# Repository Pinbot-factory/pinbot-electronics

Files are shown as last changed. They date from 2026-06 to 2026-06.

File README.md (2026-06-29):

**Pinbot** is an open-source platform for quickly building test jigs for electronics QA. The platform is made up of [mechanical fixture](https://github.com/Pinbot-factory/pinbot-mechanical), control electronics (this repo), jig-level software and backend to store all test results.

## Pinbot electronics
This repo is dedicated for electronics of a typical Pinbot jig. At a moment it is a compact carrier board for Raspberry Pi Zero [2](https://www.jeffgeerling.com/blog/2021/look-inside-raspberry-pi-zero-2-w-and-rp3a0-au/). The board also can be used with regular size RPis thru HAT connector (J3).

**It features:**
- 16 channels GPIO (0-24V) thru TCA9535
- 8 channels ADC (12 bit, 0-24V) thru ADS1015
- 4 signal relays
- USB hub
    - 4 downstream ports (3 USB-A + 1 as a pins on J2)
    - Per-port power control
    - Per-port fault signals for error and power failures handling
- Qwiic connector for easy I2C expansion
- Raspberry Pi 40-pin GPIO header with SPI, I2C, UART, etc
- USB-C for power supply
- User leds, test points, basic signal lines protection and more.

Carrier board is 114x65mm to fit perfectly into [Pinbot's chassis](https://github.com/Pinbot-factory/pinbot-mechanical/tree/main/chassis). You can use it as a test engine for a small projects and supply them (as well as connected USB periphery) with 5V.

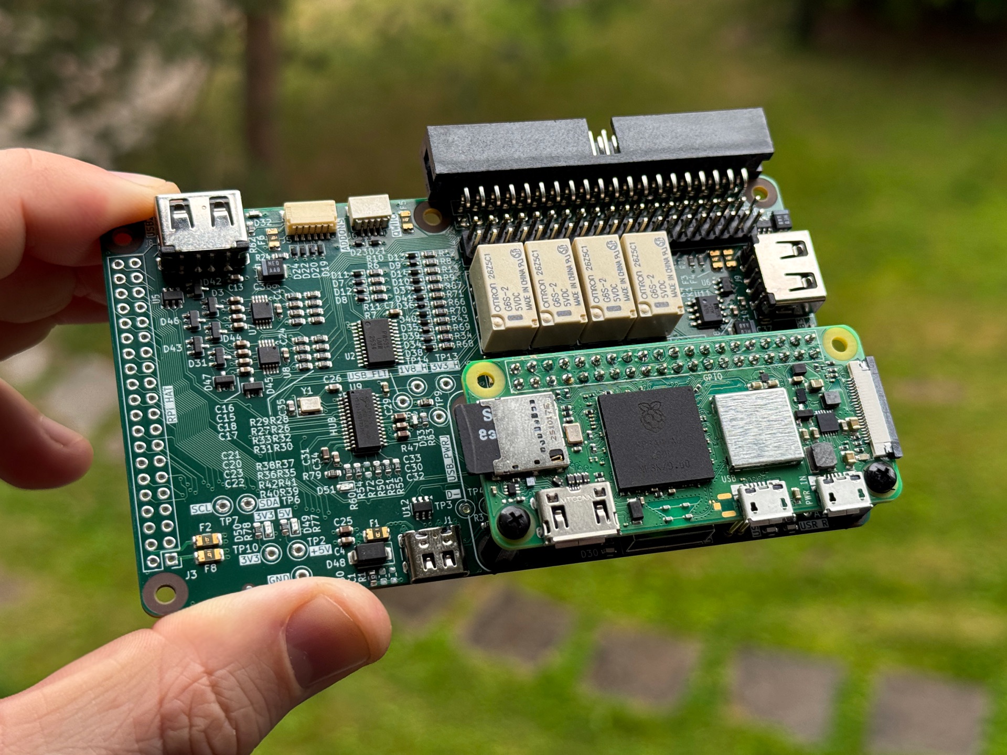
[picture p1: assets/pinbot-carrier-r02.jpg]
Pinbot PCBA


The repo includes KiCAD source files, generated gerbers, BOM, and everything to produce it on your own. Python *library and software examples* are also available and briefly [documented](sw_examples/README.md).

## License
- [GNU GPLv3](https://www.gnu.org/licenses/gpl-3.0.en.html) for **software**: firmware, libraries, generators, tools, examples, etc
- [CERN-OHL-S](https://cern-ohl.web.cern.ch/) for **hardware**: PCB schematic, layout, BOM, gerbers, 3D models, g-codes, etc.
- [CC BY-SA 4.0](https://creativecommons.org/licenses/by-sa/4.0/deed.en) is for docs, pictures, articles, video, assets, etc.

Pinbot projects structure may mix different sources and artifacts — check corresponding dirrectories for `LICENSE` file.

-----------
*This project is sponsored by [NLnet](https://nlnet.nl/) as a part of [NGI Zero Review](https://nlnet.nl/NGI0/review/) program.*
<p align="left">
    
</p>

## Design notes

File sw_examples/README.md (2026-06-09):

# Pinbot lib
The lib written specifically for the **Pinbot r0.2** board and simplifies access to all of its peripherals (relays, LEDs, and the USB hub) over the I2C bus. It also provides convenient access to 16 general-purpose I/O channels. See Pinbot [schematics](../docs/pinbot-carrier-schematic.pdf) for detailed HW architecture.

## Installation and usage
Simply copy the entire directory, including its internal structure and files, to the Raspberry Pi that controls the Pinbot board.

Here is a simple example of using the lib with a Pinbot board.
```python
import pinbot

# Init Pinbot board with it's default periphery config
board = pinbot.init_default()

board.led.on(pinbot.RED)
board.relay.close(1)

board.signal.write(
    "GPIO0",
    state=pinbot.HIGH
)

state = board.signal.read("GPIO0")
print(f"GPIO0 state = {state}")
```

You can find additional usage examples in the repo, along with a couple of tools for debugging your test jigs.

## IO1 signals mapping and pinout
TCA9535  on I2C ddress: **0x20**. General purpose IO expander. Protected GPIO channels (0-24V)

| Port | Pin | Signal Name | Default mode | J2 pin |
|---|-----|---|---|---|
| 0 | 0 | GPIO0 | out | 12 |
| 0 | 1 | GPIO1 | out | 11 |
| 0 | 2 | GPIO2 | out | 14 |
| 0 | 3 | GPIO3 | out | 13 |
| 0 | 4 | GPIO4 | out | 16 |
| 0 | 5 | GPIO5 | out | 15 |
| 0 | 6 | GPIO6 | out | 18 |
| 0 | 7 | GPIO7 | out | 17 |
| 1 | 0 | GPIO8 | out | 22 |
| 1 | 1 | GPIO9 | out | 21 |
| 1 | 2 | GPIO10 | out | 24 |
| 1 | 3 | GPIO11 | out | 23 |
| 1 | 4 | GPIO12 | out | 26 |
| 1 | 5 | GPIO13 | out | 25 |
| 1 | 6 | GPIO14 | out | 28 |
| 1 | 7 | GPIO15 | out | 27 |

## IO2 signals mapping and pinout
TCA9535 on I2C address: **0x21**. Relay control, USB control, alerts and status LEDs.

| Port | Pin | Signal Name | Default mode | Comment |
|---|-----|---|---|---|
| 0 | 0 | RELAY1 | out | Relay 1 control, J4 pins 1, 3, 5 |
| 0 | 1 | RELAY2 | out | Relay 2 control, J4 pins 7, 9, 11|
| 0 | 2 | RELAY3 | out | Relay 3 control, J4 pins 13, 15, 17 |
| 0 | 3 | RELAY4 | out | Relay 4 control, J4 pins 19, 21, 23 |
| 0 | 4 | ALERT0 | in | ADS1015 alert 0 |
| 0 | 5 | ALERT1 | in | ADS1015 alert 1 |
| 0 | 6 | USR_R | out | User **red** LED |
| 0 | 7 | USR_G | out | User **green** LED |
| 1 | 0 | USB_FLT1 | in | USB port 1 fault, **active low** |
| 1 | 1 | USB_FLT2 | in | USB port 2 fault, **active low** |
| 1 | 2 | USB_FLT3 | in | USB port 3 fault, **active low** |
| 1 | 3 | USB_FLT4 | in | USB port 4 fault, **active low** |
| 1 | 4 | USB_EN1 | out | USB port 1 enable, **active low** |
| 1 | 5 | USB_EN2 | out | USB port 2 enable, **active low** |
| 1 | 6 | USB_EN3 | out | USB port 3 enable, **active low** |
| 1 | 7 | USB_EN4 | out | USB port 4 enable, **active low** |

Pinbot is a simple library written in Python that works via `smbus2` and `lgpio` (both are included in the standard Raspbian OS distribution). It is suitable for getting familiar with the concept of test jigs and organizing "end-of-line" tests across batches of hundreds and thousands of units. However, do not expect impressive performance or the outstanding stability required for industrial automation.

## TODO
- Proper ADC lib integration
  - More ADC examples
- Example of how to use more than one instance of `pinbot()` in concurent scripts
- Detailed description on USB-hub behaviour
- Implement Active-Low mapping to `pinbot.signal.info()`
- Document whole lib calls
- Ensure USB hub availability in OS

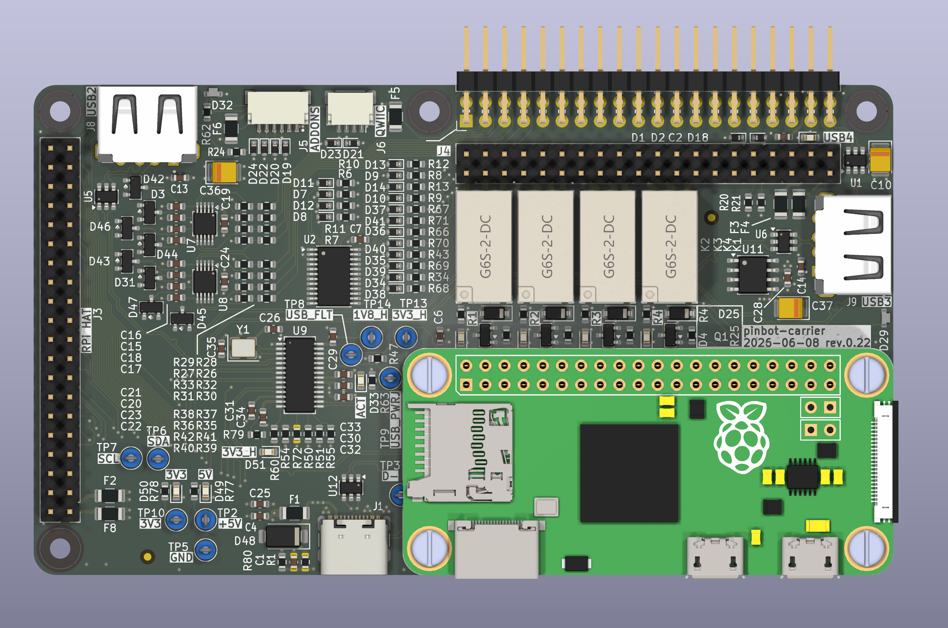
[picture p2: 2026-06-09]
assets/pinbot-pcba.png

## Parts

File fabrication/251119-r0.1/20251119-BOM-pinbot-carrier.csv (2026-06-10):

Reference | Value | Footprint | Qty | DNP | LCSC Part # | Mouser Part #
A1 | Raspberry Pi Zero v1.3 | Raspberry_Pi_Zero_v.1.3_Hat:RASPI_ZERO_FULL | 1
C1,C4,C5,C6,C7,C9,C10,C17,C18,C19,C20,C21,C22,C23 | 0.1uFx50V | Capacitor_SMD:C_0603_1608Metric | 14 |  | C282519 | CGA3E2X7R1H104M080AA
C2 | 0.01uFx50V | Capacitor_SMD:C_0603_1608Metric | 1 |  | C100042 | 06031C103K4T4A
C3,C8,C12,C13,C14 | 100uFx16V | Capacitor_SMD:CP_Elec_6.3x5.4 | 5 |  | C129250 | UWT1C101MCL1GB
C11,C15,C16 | 10uFx10V | Capacitor_SMD:C_0603_1608Metric | 3 |  | C2959727 | GRM188Z71A106MA73J
D1,D2,D3,D4,D6,D7,D8,D9 | LTST-S270KGKT | LED_0603_1608Metric_side:LED_0603_1608Metric_side | 8 |  | C125113 | LTST-S270KGKT
D5 | LTST-S270KRKT | LED_0603_1608Metric_side:LED_0603_1608Metric_side | 1 |  | C125114 | LTST-S270KRKT
D10,D11,D12,D13,D14,D15,D16,D17 | ESD5Z3.3T5G | Diode_SMD:D_SOD-523 | 8 |  | C22440077 | ESD5Z3.3T5G
F1 | MF-NSMF200-2 | Fuse:Fuse_1206_3216Metric | 1 |  | C89656 | MF-NSMF200-2
H1,H2,H3,H4 | MountingHole | MountingHoles:MountingHole_3.2mm_M3_keepouts | 4 | DNP
J1 | USB4105-GF-A-120 | Connector_USB:USB_C_Receptacle_GCT_USB4105-xx-A_16P_TopMnt_Horizontal | 1 |  | C709358 | USB4105-GF-A-120
J2 | Conn_02x20_Odd_Even | Connector_PinSocket_2.54mm:PinSocket_2x20_P2.54mm_Vertical | 1 |  | C2977589
J3 | HC-1.0-4PWT | Connector_JST:JST_SH_SM04B-SRSS-TB_1x04-1MP_P1.00mm_Horizontal | 1 |  | C2845363 | 10147606-00004LF
J4 | SM06B-SRSS-TB | SM06B-SRSS-TB:JST_SM06B-SRSS-TB | 1 |  | C160405 | 10147606-00006LF
J5,J6,J7 | USB_A | USB1125-GF-B:GCT_USB1125-GF-B_REVA | 3 |  | C5984324 | USB1125-GF-B
JP1,JP2 | SolderJumper_2_Open | Jumper:SolderJumper-2_P1.3mm_Open_RoundedPad1.0x1.5mm | 2 | DNP
K1,K2,K3,K4 | EC2-5SNU | Relay_THT:Relay_DPDT_Kemet_EC2 | 4 |  | C2153173 | EC2-5SNU
R1,R2,R3,R4,R12,R13,R14,R15 | 820k | Resistor_SMD:R_0603_1608Metric | 8 |  | C2907070 | ERJ-3EKF8203V
R5,R6,R8,R9,R16,R17,R20,R25 | 120k | Resistor_SMD:R_0603_1608Metric | 8 |  | C2930027 | CRGCQ0603F120K
R7 | 1M | Resistor_SMD:R_0603_1608Metric | 1 |  | C107698 | ASC0603-1M0FT5
R10,R11 | 5.1k | Resistor_SMD:R_0603_1608Metric | 2 |  | C2907114 | ERJ-3EKF5101V
R18,R19,R21,R22,R23,R24,R26,R27,R35,R36,R37,R42,R43 | 10k | Resistor_SMD:R_0603_1608Metric | 13 |  | C2907113 | RMC1/16K1002DTP
R28 | 100R | Resistor_SMD:R_0603_1608Metric | 1 |  | C2907089 | CRT0603-DY-1000ELF
R29,R30,R31,R32,R33,R34,R39,R40,R41 | 330R | Resistor_SMD:R_0603_1608Metric | 9 |  | C23138 | RMCF0603FT330R
R38 | 2.7k | Resistor_SMD:R_0603_1608Metric | 1 |  | C13167 | AC0603FR-102K7L
U1 | TCA9535PWR | Package_SO:TSSOP-24_4.4x7.8mm_P0.65mm | 1 |  | C22396388 | TCA9535PWR
U2,U7 | ADS1015IDGS | Package_SO:TSSOP-10_3x3mm_P0.5mm | 2 |  | C193969 | ADS1015IDGS
U8 | 74HC04 | Package_SO:SOIC-14_3.9x8.7mm_P1.27mm | 1 |  | C5590 | 74HC04D,653
U9,U10,U11,U12 | ZXBM5210-S | Package_SO:SOIC-8_3.9x4.9mm_P1.27mm | 4 |  | C20627211 | ZXBM5210-S
U13,U19 | MIC2026-2xM | Package_SO:SOIC-8_3.9x4.9mm_P1.27mm | 2 |  | C148072 | MIC2026-2YM
U14,U15,U16,U17 | USBLC6-2SC6 | Package_TO_SOT_SMD:SOT-23-6 | 4 |  | C5180249 | USBLC6-2SC6
U18 | FE1.1s | Package_SO:SSOP-28_3.9x9.9mm_P0.635mm | 1 |  | C9359
Y1 | 12MHz | Crystal:Crystal_SMD_3225-4Pin_3.2x2.5mm | 1 |  | C70565 | ECS-120-12-33-AEN-TR

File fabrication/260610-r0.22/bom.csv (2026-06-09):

Designator | Footprint | Quantity | Value | LCSC Part #
C1 | 0603 | 1 | 0.01uFx50V | C100042
C10, C36, C37, C9 | CP_EIA-3528-21_Kemet-B | 4 | 100uFx10V | C600583
C12, C13, C14, C15, C16, C17, C18, C19, C2, C20, C21, C22, C23, C24, C27, C28, C29, C30, C34, C4, C7, C8 | 0603 | 22 | 0.1uFx50V | C282519
C25, C31, C32, C33, C6 | 0603 | 5 | 10uFx10V | C2959727
C26, C35 | 0603 | 2 | 14pFx50V | C5360816
D1, D10, D11, D12, D13, D14, D19, D2, D20, D21, D22, D23, D24, D34, D35, D36, D37, D38, D39, D40, D41, D7, D8, D9 | D_SOD-523 | 24 | ESD5Z3.3T5G | C22440077
D15 | 0603 | 1 | LTST-S270KRKT | C125114
D16, D29, D30, D32 | 0603 | 4 | LTST-S270KGKT | C125113
D17, D18, D4, D5, D6 | 0603 | 5 | 19-21/GHC-YR1S2/4T | C2986048
D25, D26, D27, D28 | D_SOD-123 | 4 | MMSD4148 | C11177
D3, D31, D42, D43, D44, D45, D46, D47, D52, D53, D54, D55 | SOT-23 | 12 | BAT54S | C19726
D33, D49, D50, D51 | 0603 | 4 | XL-1608SURC-06 | C965799
D48 | D_SMA | 1 | SMAJ5.0A | C83329
F1 | 1206 | 1 | MF-NSMF200-2 | C89656
F2, F3, F4, F5, F6, F8 | 1206 | 6 | MF-NSMF110-2 | C89654
J1 | USB_C_Receptacle_GCT_USB4105-xx-A_16P_TopMnt_Horizontal | 1 | USB4105-GF-A-120 | C709358
J2 | PinHeader_2x20_P2.54mm_Horizontal | 1 | Conn_02x20_Odd_Even | C124369
J3 | PinHeader_2x20_P2.54mm_Vertical | 1 | Raspberry_Pi_4 | C19190512
J4 | PinHeader_2x20_P2.54mm_Vertical | 1 | Conn_02x20_Odd_Even | C19190512
J5 | JST_SM06B-SRSS-TB | 1 | SM06B-SRSS-TB | C160405
J6 | JST_SH_SM04B-SRSS-TB_1x04-1MP_P1.00mm_Horizontal | 1 | HC-1.0-4PWT | C2845363
J7, J8, J9 | GCT_USB1125-GF-B_REVA | 3 | USB_A | C5984324
K1, K2, K3, K4 | G6S-2-5V | 4 | G6S-2-5V | C32776
Q1, Q2, Q3, Q4 | SOT-23 | 4 | 2N7002 | C81445
R1 | 0603 | 1 | 1M | C107698
R10, R11, R12, R13, R16, R17, R18, R19, R25, R27, R29, R31, R33, R34, R36, R38, R40, R42, R43, R44, R45, R46, R47, R54, R55, R56, R57, R58, R59, R6, R66, R67, R68, R69, R7, R70, R71, R72, R73, R74, R75, R76, R8, R9 | 0603 | 44 | 10k | C98220
R14, R15, R20, R21, R4, R48, R49, R5, R52, R53, R61, R62, R63, R64, R65, R77, R78, R79 | 0603 | 18 | 330R | C23138
R2, R3 | 0603 | 2 | 5.1k | C2907114
R24 | 0603 | 1 | 100R | C2907089
R26, R28, R30, R32, R35, R37, R39, R41 | 0603 | 8 | 110k | C25805
R50, R51 | 0603 | 2 | 51k | C2907180
R60 | 0603 | 1 | 2.7k | C13167
R80 | 0603 | 1 | 0 | C95177
U1, U12, U4, U5, U6 | SOT-23-6 | 5 | USBLC6-2SC6 | C5180249
U10, U11 | SOIC-8_3.9x4.9mm_P1.27mm | 2 | MIC2026-2xM | C148072
U2, U3 | TSSOP-24_4.4x7.8mm_P0.65mm | 2 | TCA9535PWR | C22396388
U7, U8 | TSSOP-10_3x3mm_P0.5mm | 2 | ADS1015IDGS | C193969
U9 | SSOP-28_3.9x9.9mm_P0.635mm | 1 | FE1.1s | C9359
Y1 | Crystal_SMD_3225-4Pin_3.2x2.5mm | 1 | 12MHz | C70565

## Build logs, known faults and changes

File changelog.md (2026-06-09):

# Changelog

## 20260531 (r0.21)
- bugfix: TCA SCL-SDA reversed
- schematic minor updates: I2C addresses, netlabels, cleanup
- silkscreen fixes
- sw_examples added together with `pinbot` Python lib

## 20260508 (r0.2)
- Layout, schematic and BOM updated completely
- 2nd TCA9535 (TCA2) added
- USB hub schematic reworked heavily
- All periphery control pins is connected with TCA2 io expander
- ADS1015 alert pins added to TCA2
- New ADC dividers (x/12) and RC-filters
- Relays swapped from latch-type to normally-closed type
- 4 layers layout with impedance control
- Additional RPi compatible connector. Board can be used as RPi HAT now.
- 2 user leds
- Protection for all IO and external boards
- Debug features like test points, indicators, fiducials

## 20251119
- Project renamed
- Directory structure cleanup
- Manufacturing files updated

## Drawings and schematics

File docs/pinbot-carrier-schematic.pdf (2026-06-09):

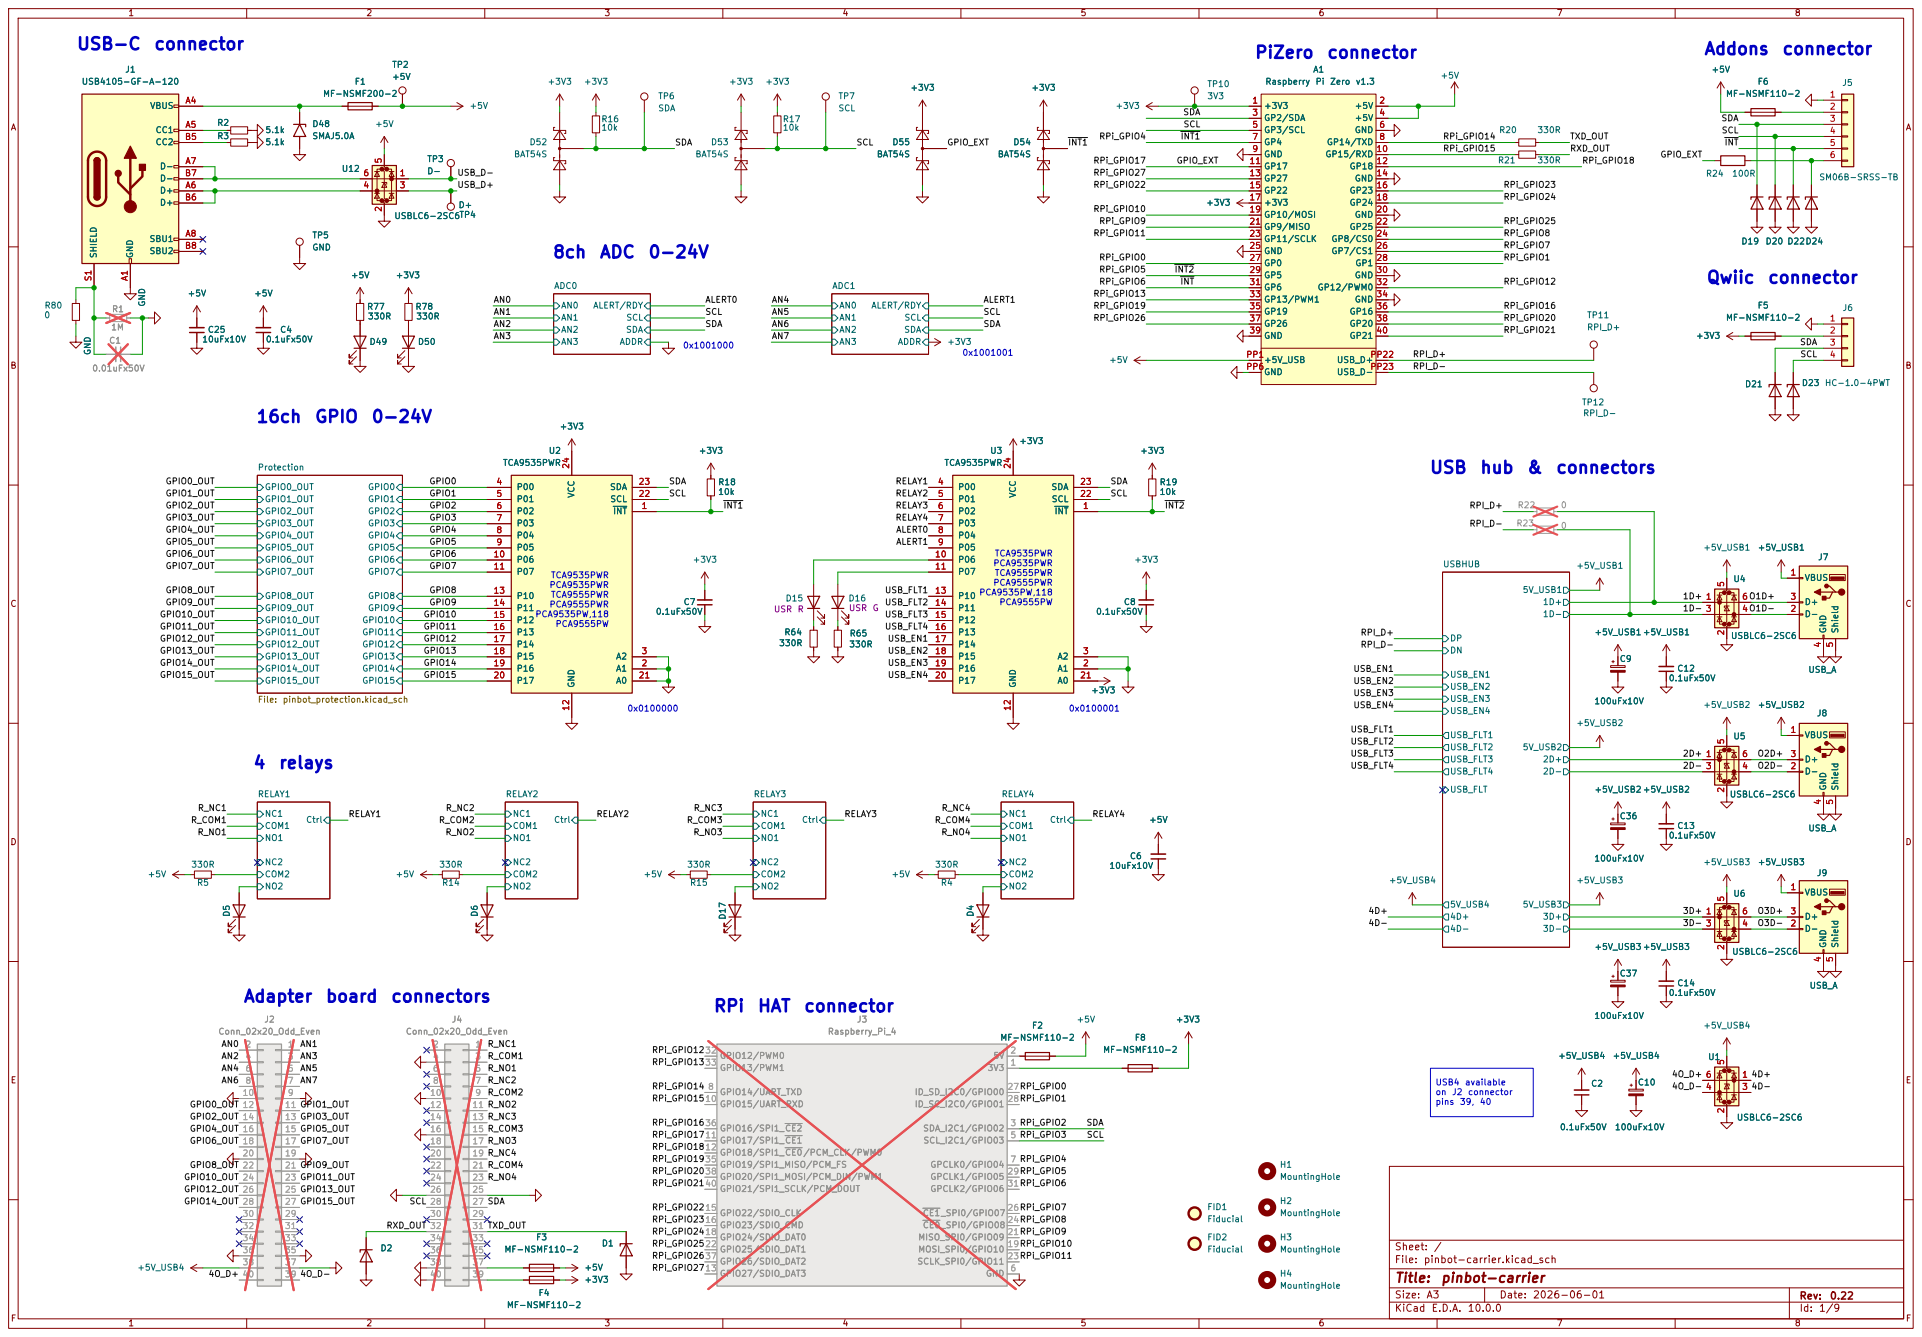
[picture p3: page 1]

Id: 1/9 Title: pinbot-carrier File: pinbot-carrier.kicad_sch Sheet: /

Size: A3 | Rev: 0.22

F Date: 2026-06-01 KiCad E.D.A. 10.0.0

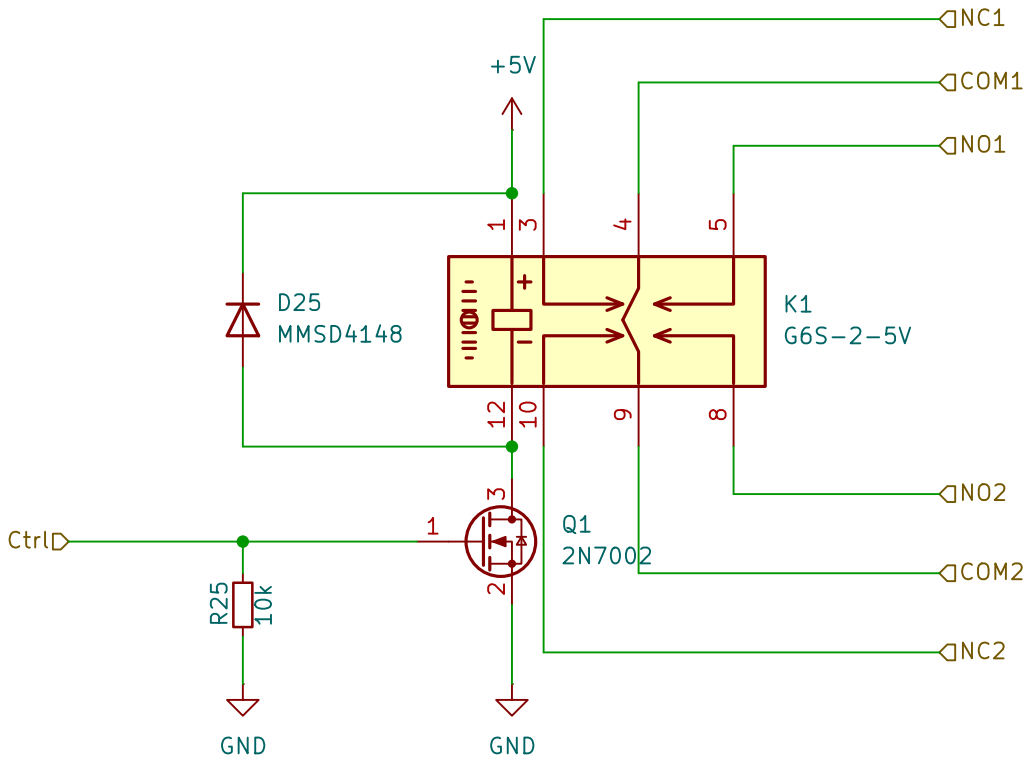
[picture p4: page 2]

Size: A4 | Rev: 0.22

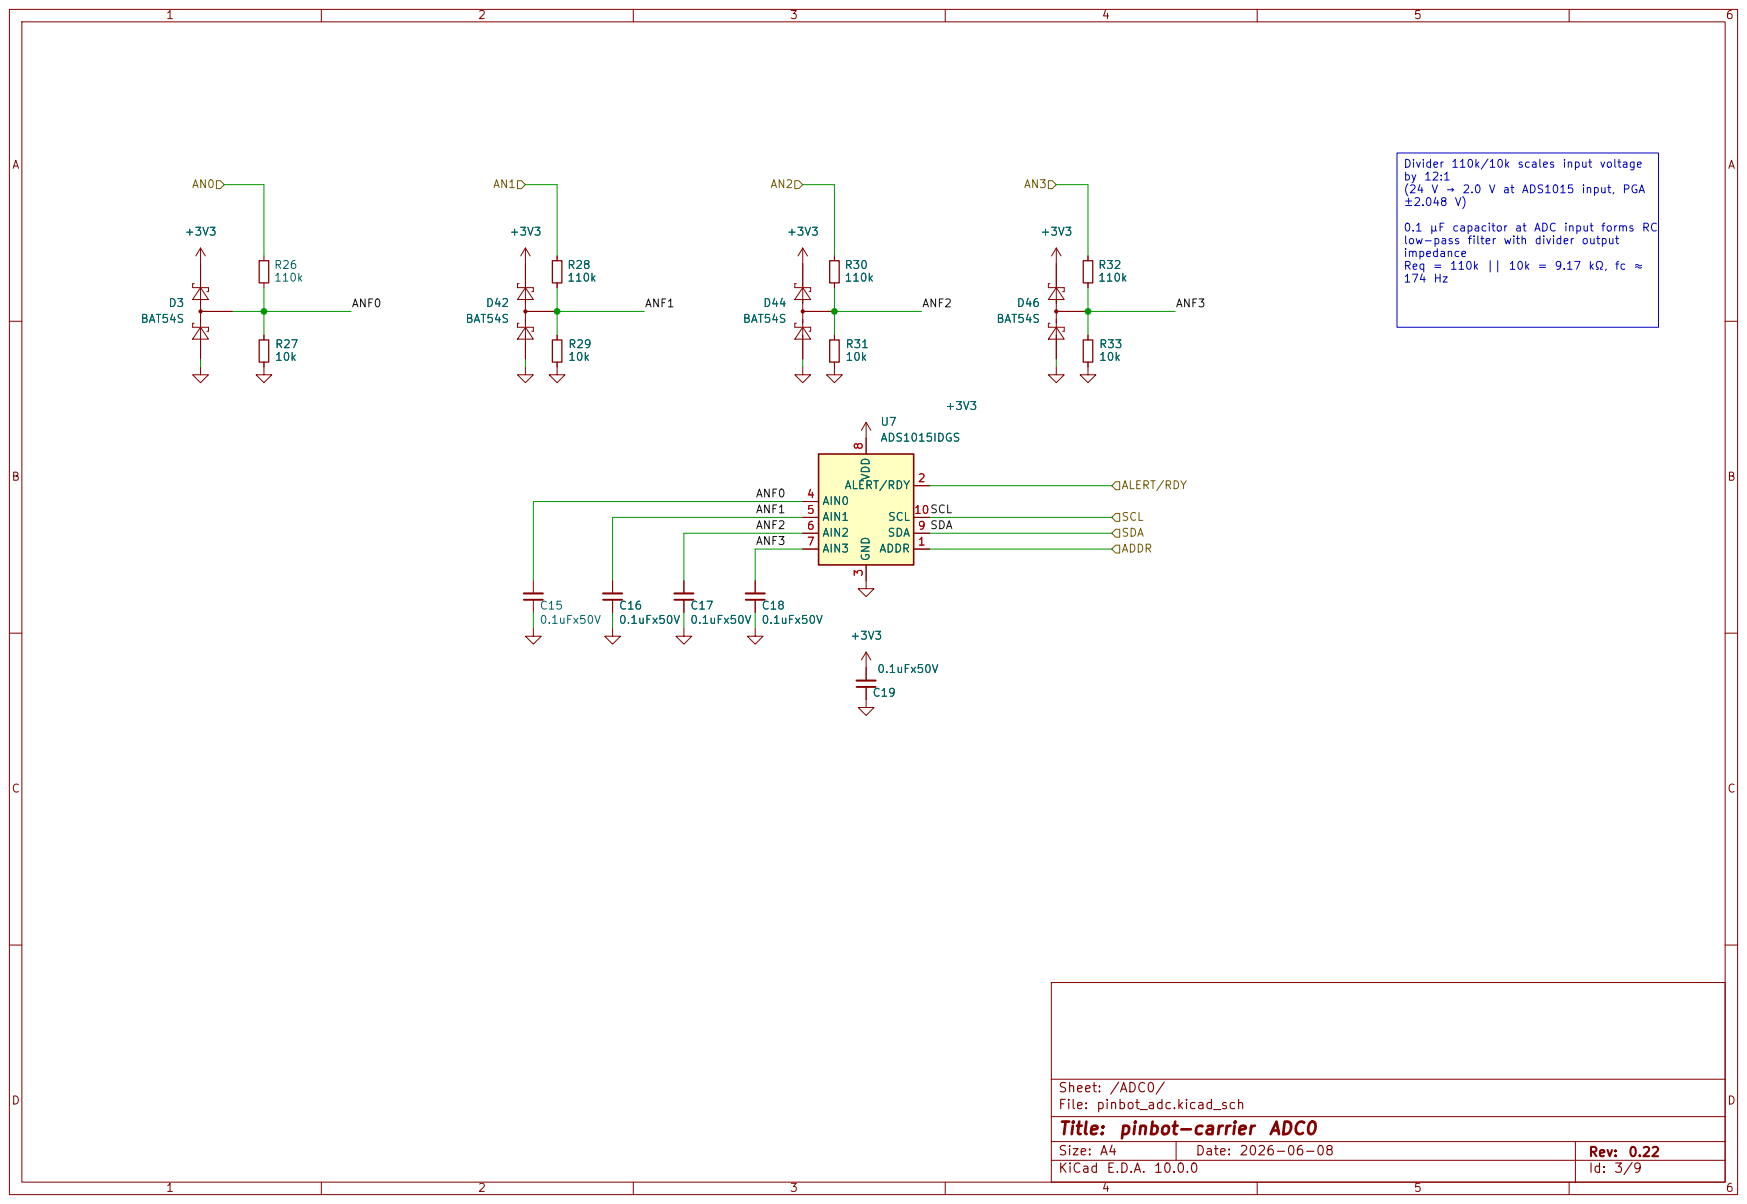
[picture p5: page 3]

0.1 µF capacitor at ADC input forms RC
low-pass filter with divider output
impedance
Req = 110k || 10k = 9.17 kΩ, fc ≈

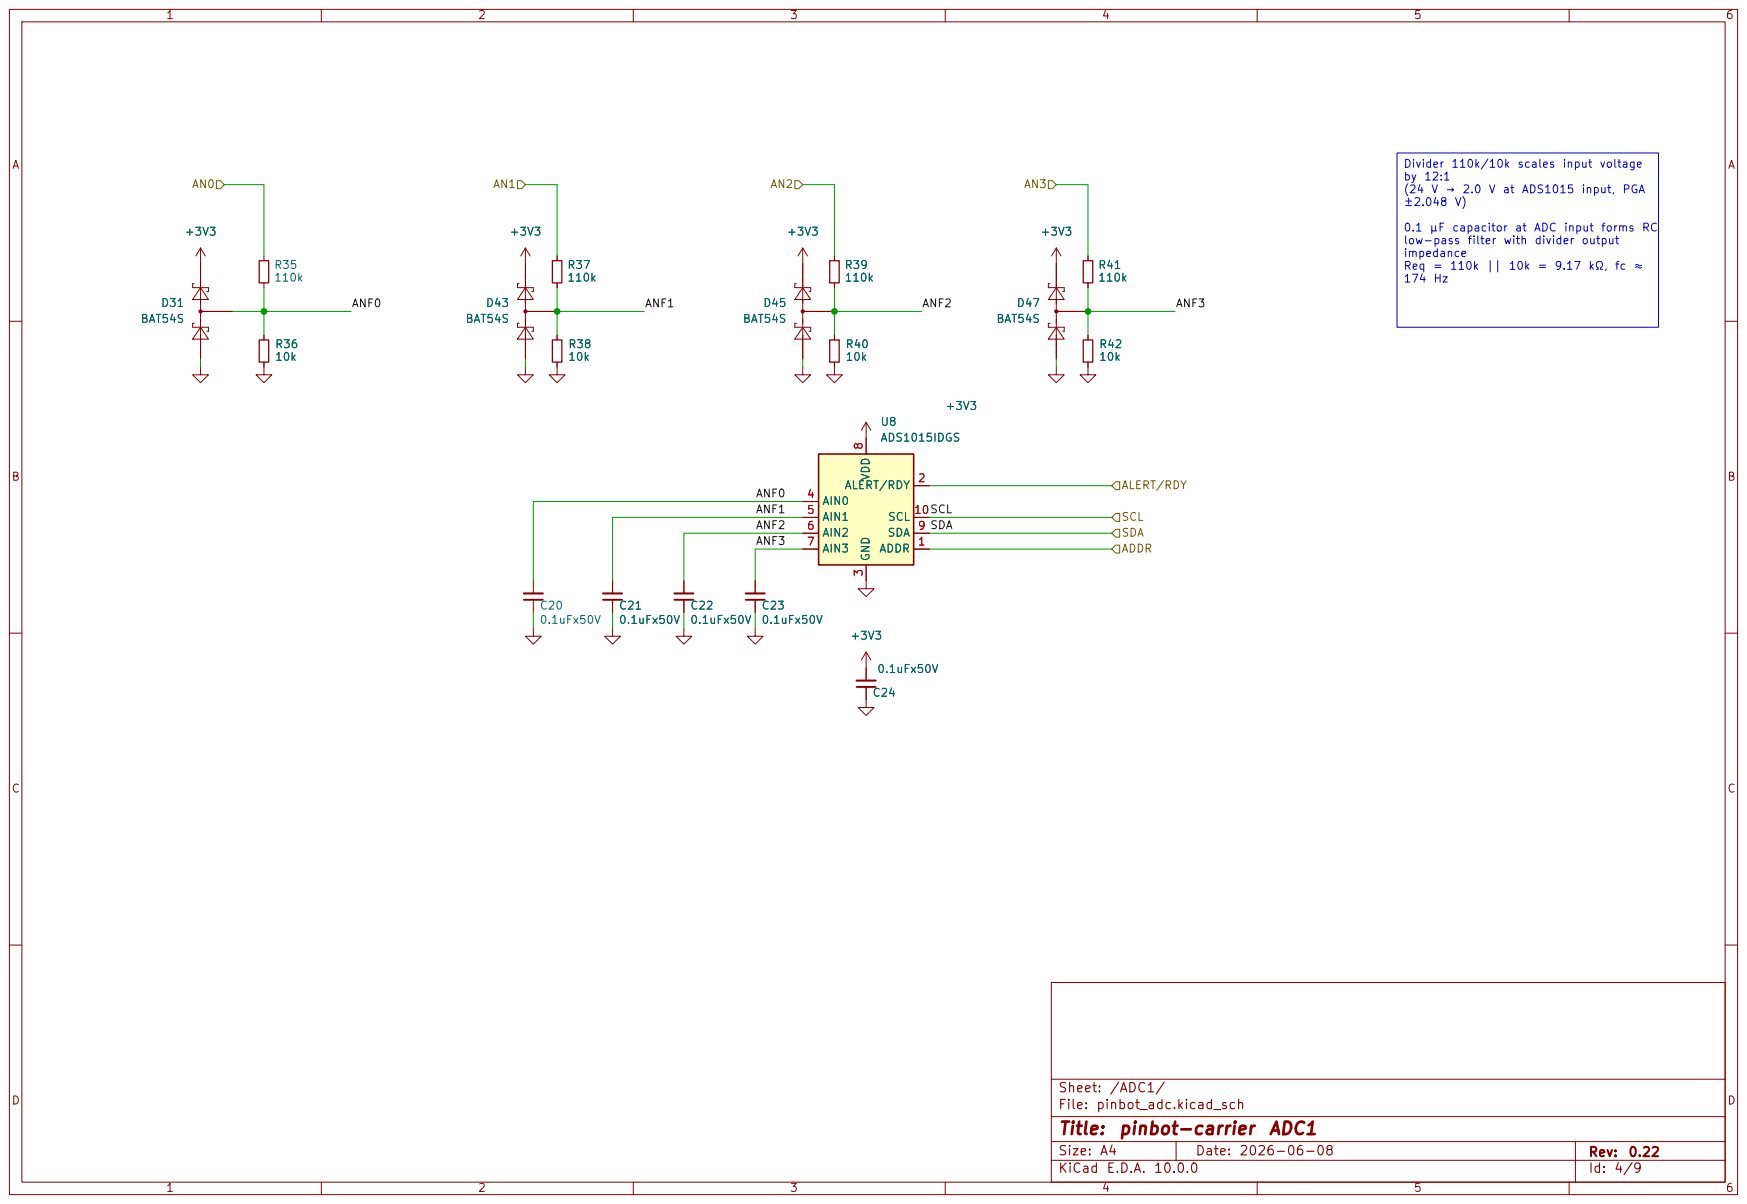
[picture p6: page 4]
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

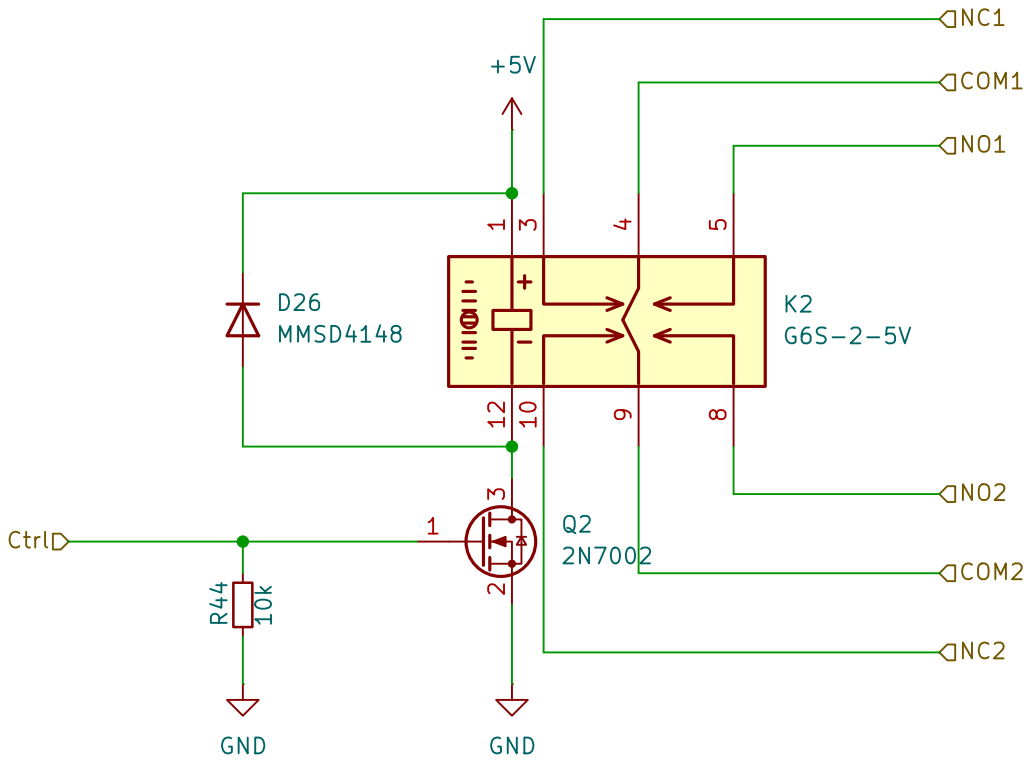
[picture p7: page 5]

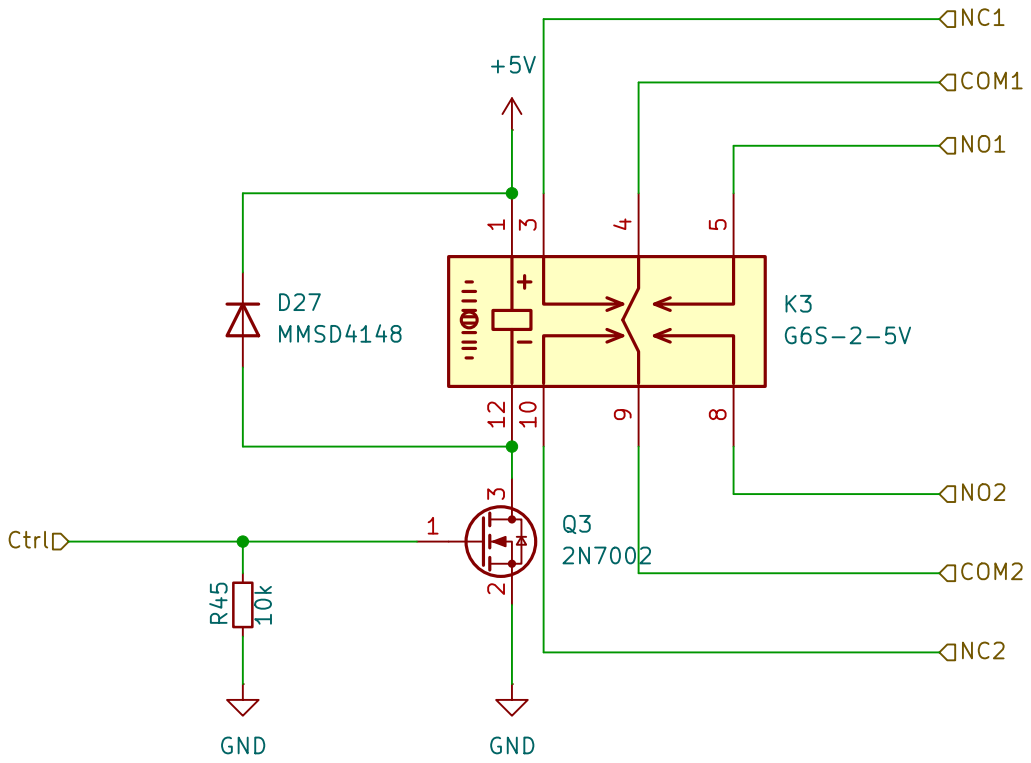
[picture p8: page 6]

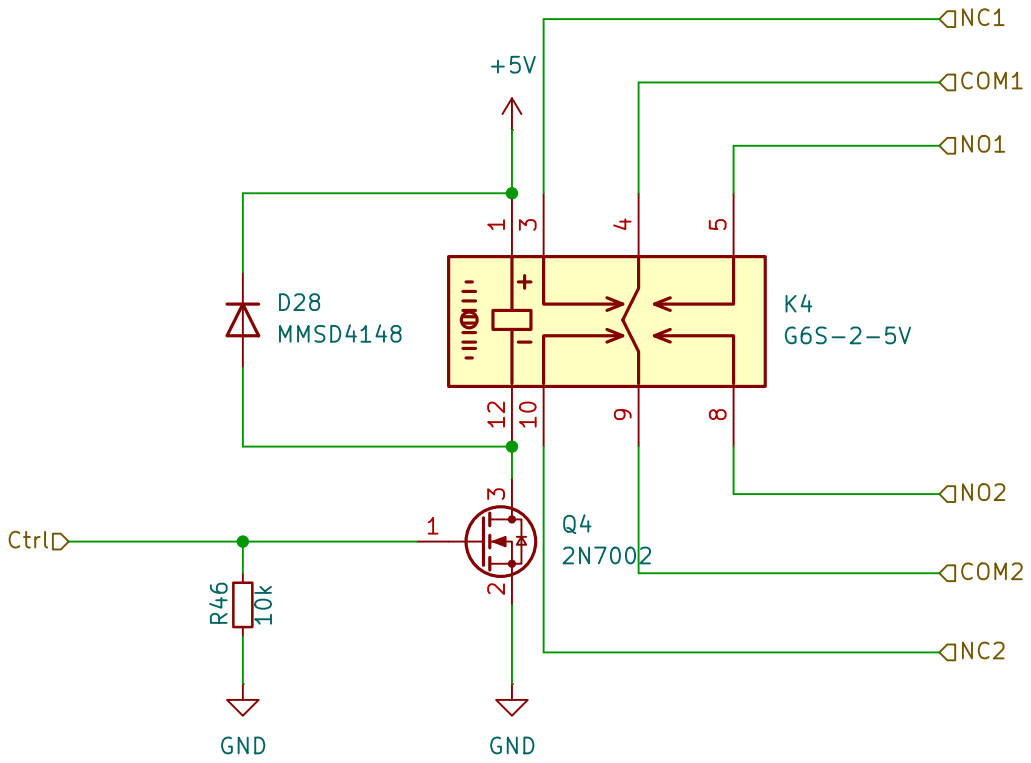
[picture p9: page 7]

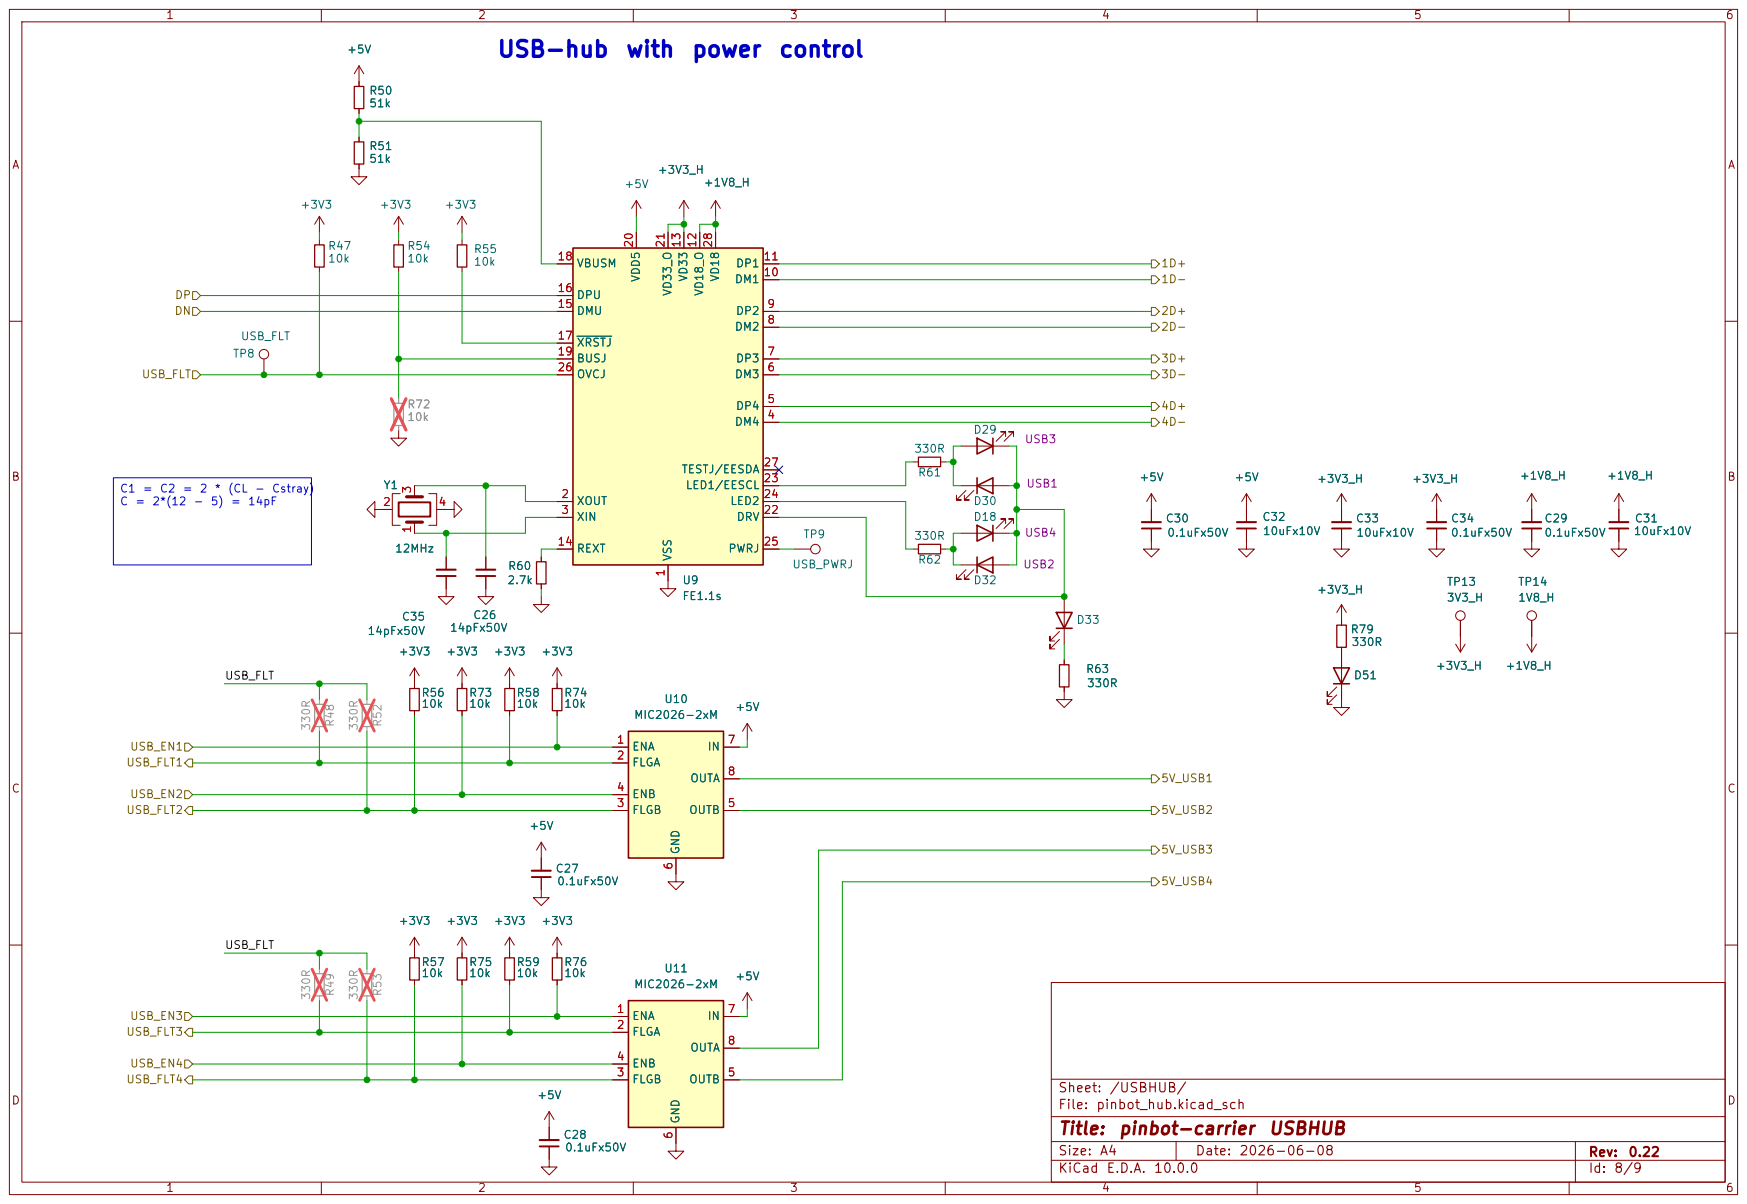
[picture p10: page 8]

Sheet: /USBHUB/
D Date: 2026-06-08 KiCad E.D.A. 10.0.0
File: pinbot_hub.kicad_sch
Title: pinbot-carrier USBHUB

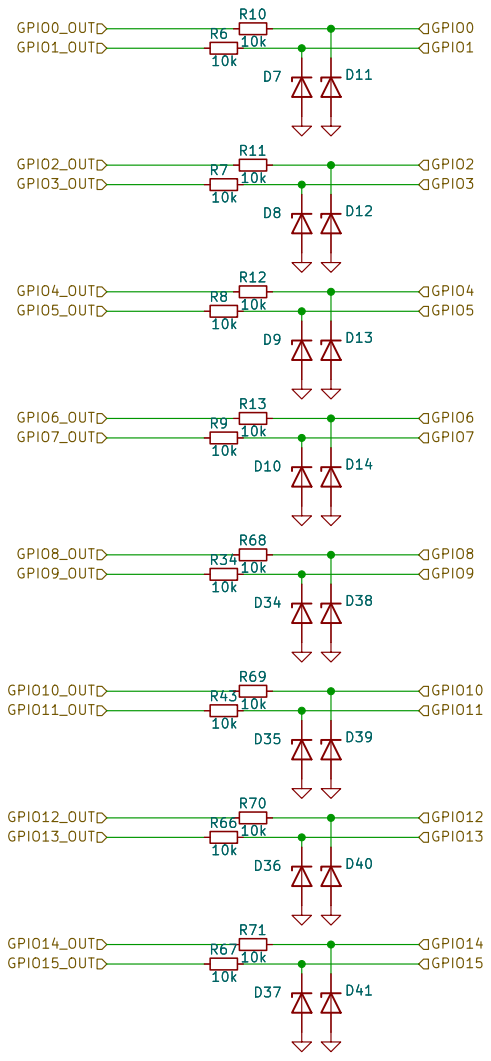
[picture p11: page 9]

Sheet: /Protection/
File: pinbot_protection.kicad_sch
Title: pinbot-carrier Protection

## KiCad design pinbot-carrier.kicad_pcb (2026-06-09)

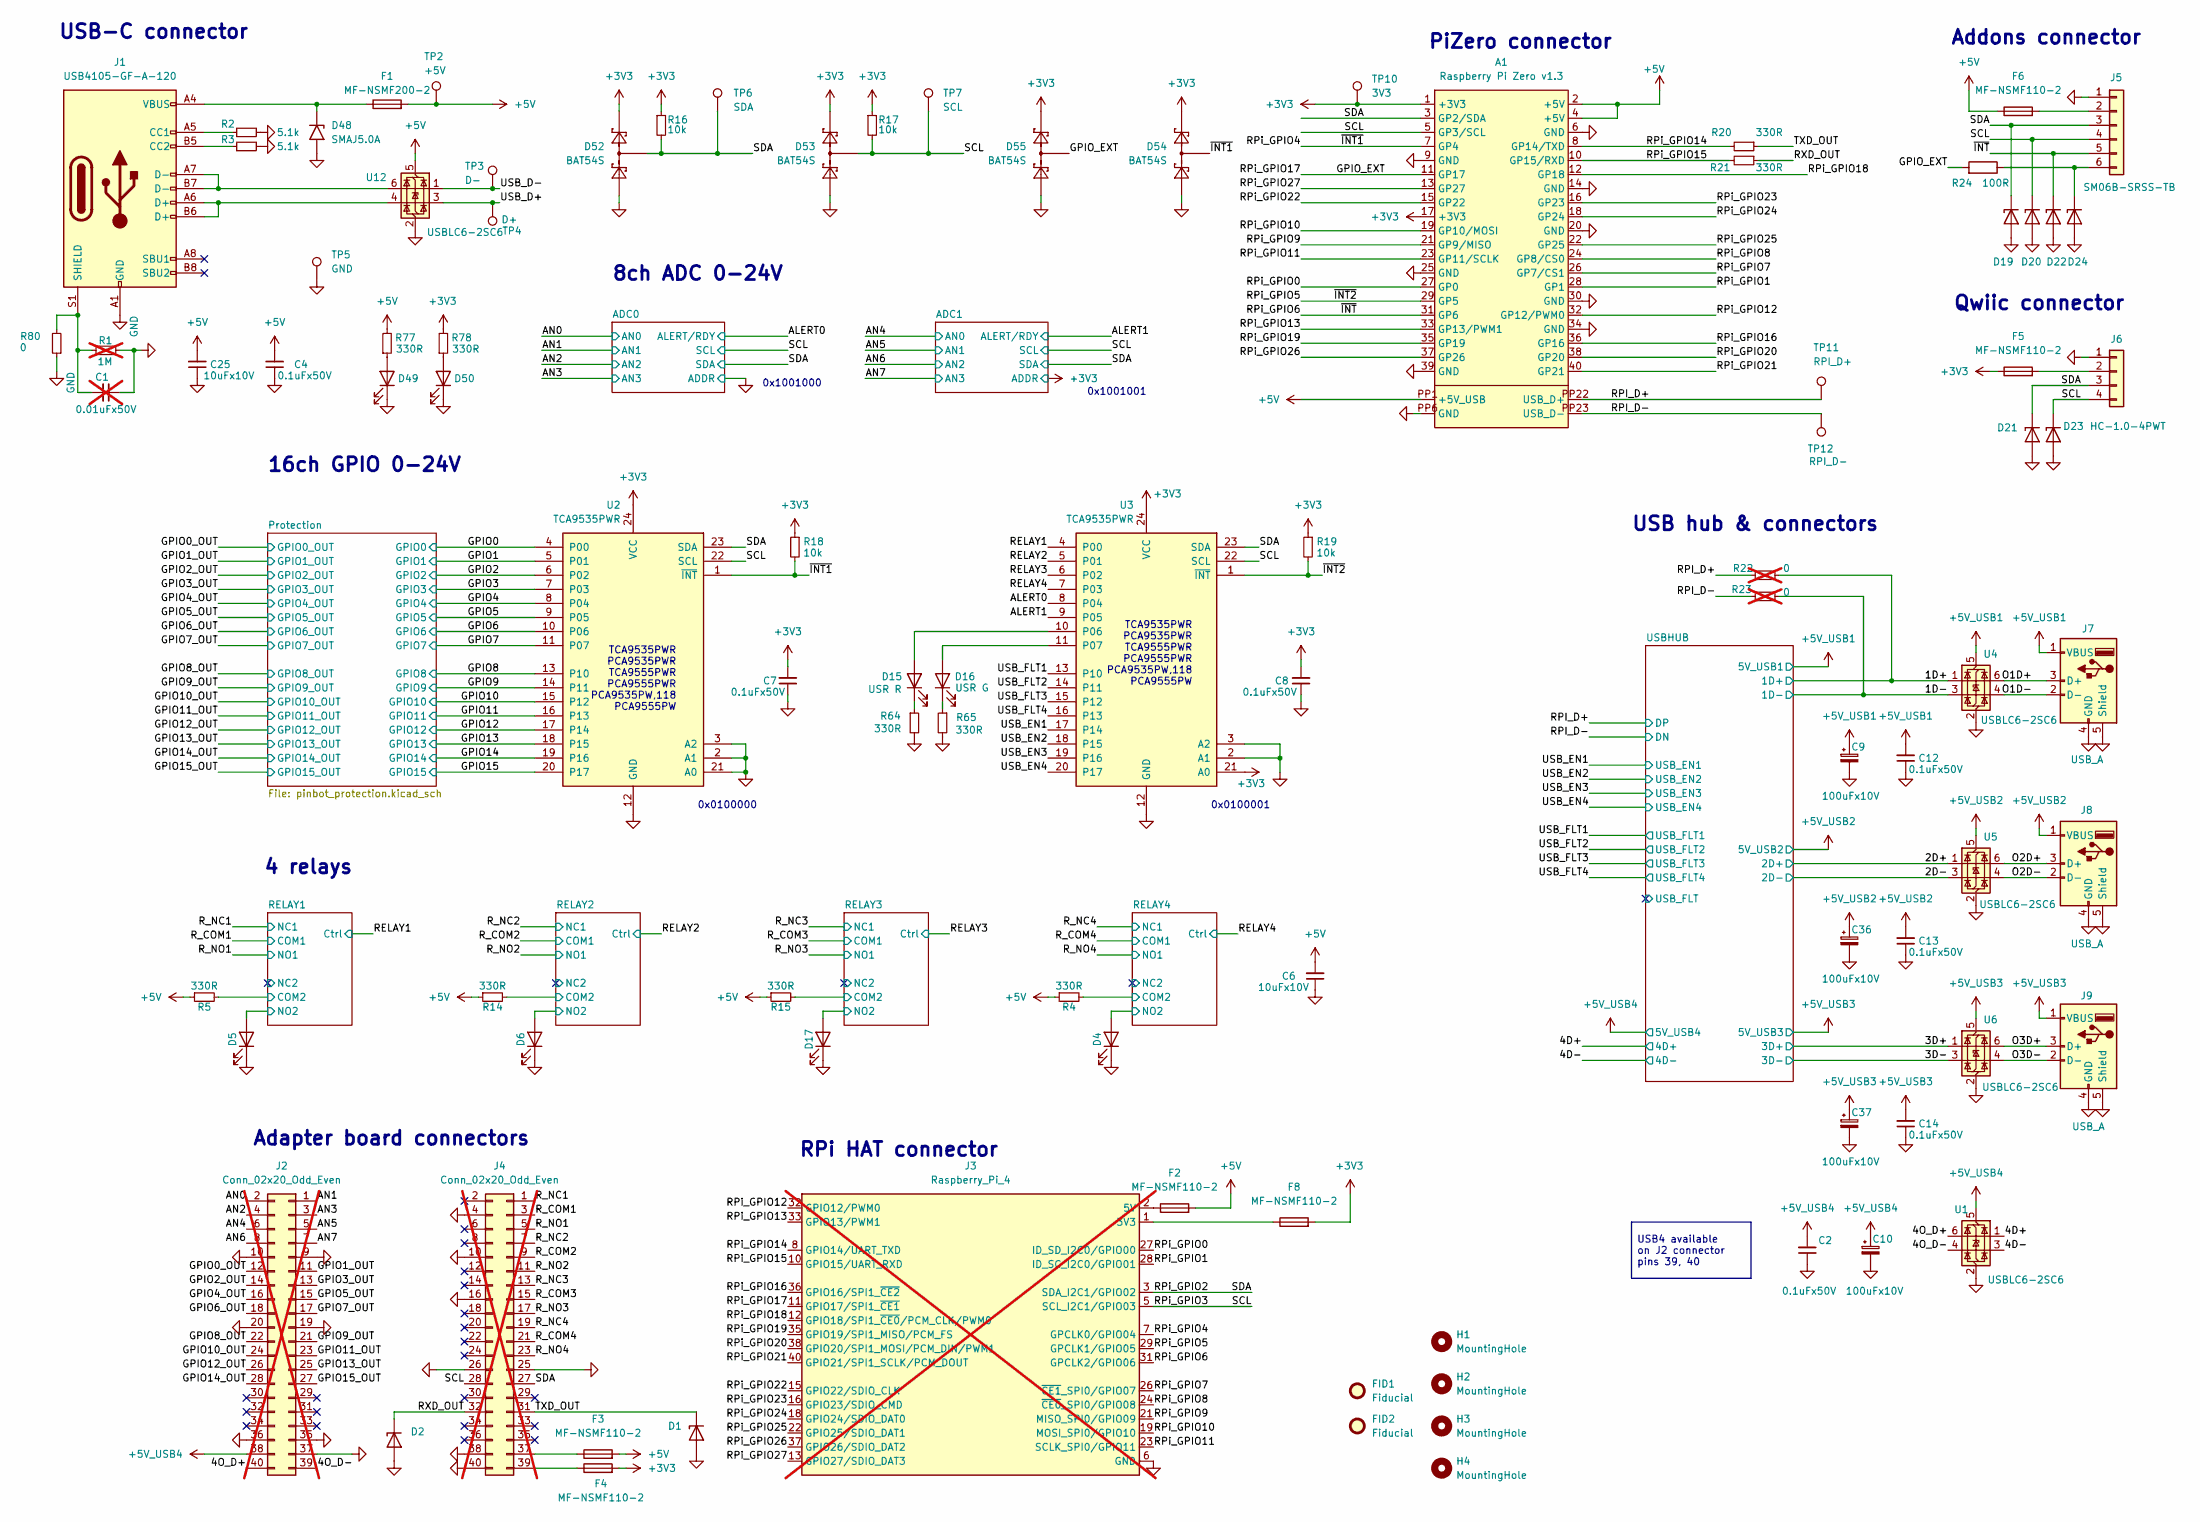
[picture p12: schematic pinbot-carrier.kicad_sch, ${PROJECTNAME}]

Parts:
A1: Raspberry Pi Zero v1.3; RASPI_ZERO_FULL; LCSC Part # C2977589
C1: 0.01uFx50V; C_0603_1608Metric; Mouser Part # 06031C103K4T4A; LCSC Part # C100042; not fitted
C2, C4, C12, C13, C14: 0.1uFx50V; C_0603_1608Metric; Mouser Part # CGA3E2X7R1H104M080AA; LCSC Part # C282519
C6, C25: 10uFx10V; C_0603_1608Metric; Mouser Part # GRM188Z71A106MA73J; LCSC Part # C2959727
C7, C8: 0.1uFx50V; C_0603_1608Metric; Mouser Part # CGA3E2X7R1H104M080AA
C9, C10, C36, C37: 100uFx10V; CP_EIA-3528-21_Kemet-B; LCSC Part # C600583
D1, D2, D19, D20, D21, D22, D23, D24: ESD5Z3.3T5G; D_SOD-523; Mouser Part # ESD5Z3.3T5G
D4, D5, D6, D17: 19-21/GHC-YR1S2/4T; LED_0603_1608Metric; LCSC Part # C2986048
D15: LTST-S270KRKT; LED_0603_1608Metric_side; Mouser Part # LTST-S270KRKT; LCSC Part # C125114
D16: LTST-S270KGKT; LED_0603_1608Metric_side; Mouser Part # LTST-S270KGKT; LCSC Part # C125113
D48: SMAJ5.0A; D_SMA; LCSC Part # C83329
D49, D50: XL-1608SURC-06; LED_0603_1608Metric; LCSC Part # C965799
D52, D53, D54, D55: BAT54S; SOT-23; LCSC Part # C19726
F1: MF-NSMF200-2; Fuse_1206_3216Metric; Mouser Part # MF-NSMF200-2; LCSC Part # C89656
F2, F3, F4, F5, F6, F8: MF-NSMF110-2; Fuse_1206_3216Metric; Mouser Part # MF-NSMF110-2; LCSC Part # C89654
FID1, FID2: Fiducial; Fiducial_1mm_Mask2mm
H1, H2, H3, H4: MountingHole; MountingHole_2.7mm
J1: USB4105-GF-A-120; USB_C_Receptacle_GCT_USB4105-xx-A_16P_TopMnt_Horizontal; Mouser Part # USB4105-GF-A-120
J2: Conn_02x20_Odd_Even; PinHeader_2x20_P2.54mm_Horizontal; LCSC Part # C124369; not fitted
J3: Raspberry_Pi_4; PinHeader_2x20_P2.54mm_Vertical; Manufacturer Part P125-1220A0BS116A1; LCSC Part # C19190512; not fitted
J4: Conn_02x20_Odd_Even; PinHeader_2x20_P2.54mm_Vertical; LCSC Part # C19190512; not fitted
J5: SM06B-SRSS-TB; JST_SM06B-SRSS-TB; Mouser Part # 10147606-00006LF; LCSC Part # C160405
J6: HC-1.0-4PWT; JST_SH_SM04B-SRSS-TB_1x04-1MP_P1.00mm_Horizontal; Mouser Part # 10147606-00004LF; LCSC Part # C2845363
J7, J8, J9: USB_A; GCT_USB1125-GF-B_REVA; Mouser Part # USB1125-GF-B
R1: 1M; R_0603_1608Metric; Mouser Part # ASC0603-1M0FT5; LCSC Part # C107698; not fitted
R2, R3: 5.1k; R_0603_1608Metric; Mouser Part # ERJ-3EKF5101V; LCSC Part # C2907114
R4, R5, R14, R15, R20, R21, R64, R65, R77, R78: 330R; R_0603_1608Metric; Mouser Part # RMCF0603FT330R; LCSC Part # C23138
R16, R17, R18, R19: 10k; R_0603_1608Metric; Mouser Part # RMC1/16K1002DTP; LCSC Part # C98220
R22, R23: 0; R_0603_1608Metric; Mouser Part # ERJ-3EKF5101V; LCSC Part # C95177; not fitted
R24: 100R; R_0603_1608Metric; Mouser Part # CRT0603-DY-1000ELF; LCSC Part # C2907089
R80: 0; R_0603_1608Metric; Mouser Part # ERJ-3EKF5101V; LCSC Part # C95177
TP2: +5V; TestPoint_Loop_D1.80mm_Drill1.0mm_Beaded
TP3: D-; TestPoint_Loop_D1.80mm_Drill1.0mm_Beaded
TP4: D+; TestPoint_Loop_D1.80mm_Drill1.0mm_Beaded
TP5: GND; TestPoint_Loop_D1.80mm_Drill1.0mm_Beaded
TP6: SDA; TestPoint_Loop_D1.80mm_Drill1.0mm_Beaded
TP7: SCL; TestPoint_Loop_D1.80mm_Drill1.0mm_Beaded
TP10: 3V3; TestPoint_Loop_D1.80mm_Drill1.0mm_Beaded
TP11: RPI_D+; TestPoint_Loop_D1.80mm_Drill1.0mm_Beaded
TP12: RPI_D-; TestPoint_Loop_D1.80mm_Drill1.0mm_Beaded
U1, U4, U5, U6, U12: USBLC6-2SC6; SOT-23-6; Mouser Part # USBLC6-2SC6
U2, U3: TCA9535PWR; TSSOP-24_4.4x7.8mm_P0.65mm; Mouser Part # TCA9535PWR

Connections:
+3V3: A1.1 (+3V3), A1.17 (+3V3), C7.2, C8.2, D52.2 (K), D53.2 (K), D54.2 (K), D55.2 (K), F4.2, F5.1, F8.2, R16.1, R17.1, R18.1, R19.1, R78.2, TP10.1 (1_1), U2.24 (VCC), U3.21 (A0), U3.24 (VCC); also elsewhere on the board
+5V: A1.2 (+5V), A1.4 (+5V), A1.PP1 (+5V_USB), C4.2, C6.2, C25.2, F1.2, F2.2, F3.2, F6.1, R4.1, R5.1, R14.1, R15.1, R77.2, TP2.1 (1_1), U12.5 (VBUS); also elsewhere on the board
+5V_USB1: C9.1, C12.2, J7.1 (VBUS), U4.5 (VBUS); also elsewhere on the board
+5V_USB2: C13.2, C36.1, J8.1 (VBUS), U5.5 (VBUS); also elsewhere on the board
+5V_USB3: C14.2, C37.1, J9.1 (VBUS), U6.5 (VBUS); also elsewhere on the board
+5V_USB4: C2.2, C10.1, J2.38, U1.5 (VBUS); also elsewhere on the board
/1D+: R22.2, U4.1 (I/O1); also elsewhere on the board
/1D-: R23.2, U4.3 (I/O2); also elsewhere on the board
/2D+: U5.1 (I/O1); also elsewhere on the board
/2D-: U5.3 (I/O2); also elsewhere on the board
/3D+: U6.1 (I/O1); also elsewhere on the board
/3D-: U6.3 (I/O2); also elsewhere on the board
/4D+: U1.1 (I/O1); also elsewhere on the board
/4D-: U1.3 (I/O2); also elsewhere on the board
/4O_D+: J2.40, U1.6 (I/O1)
/4O_D-: J2.39, U1.4 (I/O2)
/ALERT0: U3.8 (P04); also elsewhere on the board
/ALERT1: U3.9 (P05); also elsewhere on the board
/AN0: J2.2; also elsewhere on the board
/AN1: J2.1; also elsewhere on the board
/AN2: J2.4; also elsewhere on the board
/AN3: J2.3; also elsewhere on the board
/AN4: J2.6; also elsewhere on the board
/AN5: J2.5; also elsewhere on the board
/AN6: J2.8; also elsewhere on the board
/AN7: J2.7; also elsewhere on the board
/GPIO0: U2.4 (P00); also elsewhere on the board
/GPIO0_OUT: J2.12; also elsewhere on the board
/GPIO1: U2.5 (P01); also elsewhere on the board
/GPIO1_OUT: J2.11; also elsewhere on the board
/GPIO2: U2.6 (P02); also elsewhere on the board
/GPIO2_OUT: J2.14; also elsewhere on the board
/GPIO3: U2.7 (P03); also elsewhere on the board
/GPIO3_OUT: J2.13; also elsewhere on the board
/GPIO4: U2.8 (P04); also elsewhere on the board
/GPIO4_OUT: J2.16; also elsewhere on the board
/GPIO5: U2.9 (P05); also elsewhere on the board
/GPIO5_OUT: J2.15; also elsewhere on the board
/GPIO6: U2.10 (P06); also elsewhere on the board
/GPIO6_OUT: J2.18; also elsewhere on the board
/GPIO7: U2.11 (P07); also elsewhere on the board
/GPIO7_OUT: J2.17; also elsewhere on the board
/GPIO8: U2.13 (P10); also elsewhere on the board
/GPIO8_OUT: J2.22; also elsewhere on the board
/GPIO9: U2.14 (P11); also elsewhere on the board
/GPIO9_OUT: J2.21; also elsewhere on the board
/GPIO10: U2.15 (P12); also elsewhere on the board
/GPIO10_OUT: J2.24; also elsewhere on the board
/GPIO11: U2.16 (P13); also elsewhere on the board
/GPIO11_OUT: J2.23; also elsewhere on the board
/GPIO12: U2.17 (P14); also elsewhere on the board
/GPIO12_OUT: J2.26; also elsewhere on the board
/GPIO13: U2.18 (P15); also elsewhere on the board
/GPIO13_OUT: J2.25; also elsewhere on the board
/GPIO14: U2.19 (P16); also elsewhere on the board
/GPIO14_OUT: J2.28; also elsewhere on the board
/GPIO15: U2.20 (P17); also elsewhere on the board
/GPIO15_OUT: J2.27; also elsewhere on the board
/GPIO_EXT: A1.11 (GP17), D55.3 (COM), J3.11 (GPIO17/SPI1_~CE1), R24.2
/O1D+: J7.3 (D+), U4.6 (I/O1)
/O1D-: J7.2 (D-), U4.4 (I/O2)
/O2D+: J8.3 (D+), U5.6 (I/O1)
/O2D-: J8.2 (D-), U5.4 (I/O2)
/O3D+: J9.3 (D+), U6.6 (I/O1)
/O3D-: J9.2 (D-), U6.4 (I/O2)
/RELAY1: U3.4 (P00); also elsewhere on the board
/RELAY1/COM2: R5.2; also elsewhere on the board
/RELAY1/NO2: D5.2 (A); also elsewhere on the board
/RELAY2: U3.5 (P01); also elsewhere on the board
/RELAY2/COM2: R14.2; also elsewhere on the board
/RELAY2/NO2: D6.2 (A); also elsewhere on the board
/RELAY3: U3.6 (P02); also elsewhere on the board
/RELAY3/COM2: R15.2; also elsewhere on the board
/RELAY3/NO2: D17.2 (A); also elsewhere on the board
/RELAY4: U3.7 (P03); also elsewhere on the board
/RELAY4/COM2: R4.2; also elsewhere on the board
/RELAY4/NO2: D4.2 (A); also elsewhere on the board
/RPI_D+: A1.PP22 (USB_D+), R22.1, TP11.1 (1_1); also elsewhere on the board
/RPI_D-: A1.PP23 (USB_D-), R23.1, TP12.1 (1_1); also elsewhere on the board
/RPi_GPIO0: A1.27 (GP0), J3.27 (ID_SD_I2C0/GPIO00)
/RPi_GPIO1: A1.28 (GP1), J3.28 (ID_SC_I2C0/GPIO01)
/RPi_GPIO2: A1.3 (GP2/SDA), D19.1 (K), D21.1 (K), D52.3 (COM), J3.3 (SDA_I2C1/GPIO02), J4.27, J5.3, J6.3, R16.2, TP6.1 (1_1), U2.23 (SDA), U3.23 (SDA); also elsewhere on the board
/RPi_GPIO3: A1.5 (GP3/SCL), D20.1 (K), D23.1 (K), D53.3 (COM), J3.5 (SCL_I2C1/GPIO03), J4.28, J5.4, J6.4, R17.2, TP7.1 (1_1), U2.22 (SCL), U3.22 (SCL); also elsewhere on the board
/RPi_GPIO4: A1.7 (GP4), D54.3 (COM), J3.7 (GPCLK0/GPIO04), R18.2, U2.1 (~INT)
/RPi_GPIO5: A1.29 (GP5), J3.29 (GPCLK1/GPIO05), R19.2, U3.1 (~INT)
/RPi_GPIO6: A1.31 (GP6), D22.1 (K), J3.31 (GPCLK2/GPIO06), J5.5
/RPi_GPIO7: A1.26 (GP7/CS1), J3.26 (~CE1_SPI0/GPIO07)
/RPi_GPIO8: A1.24 (GP8/CS0), J3.24 (~CE0_SPI0/GPIO08)
/RPi_GPIO9: A1.21 (GP9/MISO), J3.21 (MISO_SPI0/GPIO09)
/RPi_GPIO10: A1.19 (GP10/MOSI), J3.19 (MOSI_SPI0/GPIO10)
/RPi_GPIO11: A1.23 (GP11/SCLK), J3.23 (SCLK_SPI0/GPIO11)
/RPi_GPIO12: A1.32 (GP12/PWM0), J3.32 (GPIO12/PWM0)
/RPi_GPIO13: A1.33 (GP13/PWM1), J3.33 (GPIO13/PWM1)
/RPi_GPIO14: A1.8 (GP14/TXD), J3.8 (GPIO14/UART_TXD), R20.2
/RPi_GPIO15: A1.10 (GP15/RXD), J3.10 (GPIO15/UART_RXD), R21.2
/RPi_GPIO16: A1.36 (GP16), J3.36 (GPIO16/SPI1_~CE2)
/RPi_GPIO18: A1.12 (GP18), J3.12 (GPIO18/SPI1_~CE0/PCM_CLK/PWM0)
/RPi_GPIO19: A1.35 (GP19), J3.35 (GPIO19/SPI1_MISO/PCM_FS)
/RPi_GPIO20: A1.38 (GP20), J3.38 (GPIO20/SPI1_MOSI/PCM_DIN/PWM1)
/RPi_GPIO21: A1.40 (GP21), J3.40 (GPIO21/SPI1_SCLK/PCM_DOUT)
/RPi_GPIO22: A1.15 (GP22), J3.15 (GPIO22/SDIO_CLK)
/RPi_GPIO23: A1.16 (GP23), J3.16 (GPIO23/SDIO_CMD)
/RPi_GPIO24: A1.18 (GP24), J3.18 (GPIO24/SDIO_DAT0)
/RPi_GPIO25: A1.22 (GP25), J3.22 (GPIO25/SDIO_DAT1)
/RPi_GPIO26: A1.37 (GP26), J3.37 (GPIO26/SDIO_DAT2)
/RPi_GPIO27: A1.13 (GP27), J3.13 (GPIO27/SDIO_DAT3)
/RXD_OUT: D2.1 (K), J4.32, R21.1
/R_COM1: J4.3; also elsewhere on the board
/R_COM2: J4.9; also elsewhere on the board
/R_COM3: J4.15; also elsewhere on the board
/R_COM4: J4.21; also elsewhere on the board
/R_NC1: J4.1; also elsewhere on the board
/R_NC2: J4.7; also elsewhere on the board
/R_NC3: J4.13; also elsewhere on the board
/R_NC4: J4.19; also elsewhere on the board
/R_NO1: J4.5; also elsewhere on the board
/R_NO2: J4.11; also elsewhere on the board
/R_NO3: J4.17; also elsewhere on the board
/R_NO4: J4.23; also elsewhere on the board
/TXD_OUT: D1.1 (K), J4.31, R20.1
/USB_D+: TP4.1 (1_1), U12.3 (I/O2)
/USB_D-: TP3.1 (1_1), U12.1 (I/O1)
/USB_EN1: U3.17 (P14); also elsewhere on the board
/USB_EN2: U3.18 (P15); also elsewhere on the board
/USB_EN3: U3.19 (P16); also elsewhere on the board
/USB_EN4: U3.20 (P17); also elsewhere on the board
/USB_FLT1: U3.13 (P10); also elsewhere on the board
/USB_FLT2: U3.14 (P11); also elsewhere on the board
/USB_FLT3: U3.15 (P12); also elsewhere on the board
/USB_FLT4: U3.16 (P13); also elsewhere on the board
GND: A1.6 (GND), A1.9 (GND), A1.14 (GND), A1.20 (GND), A1.25 (GND), A1.30 (GND), A1.34 (GND), A1.39 (GND), A1.PP6 (GND), C1.1, C2.1, C4.1, C6.1, C7.1, C8.1, C9.2, C10.2, C12.1, C13.1, C14.1, C25.1, C36.2, C37.2, D1.2 (A), D2.2 (A), D4.1 (K), D5.1 (K), D6.1 (K), D17.1 (K), D19.2 (A), D20.2 (A), D21.2 (A), D22.2 (A), D23.2 (A), D24.2 (A), D48.2 (A2), D49.1 (K), D50.1 (K), D52.1 (A), D53.1 (A), D54.1 (A), D55.1 (A), J1.A1 (GND), J1.A12 (GND), J1.B1 (GND), J1.B12 (GND), J2.9, J2.10, J2.19, J2.20, J2.35, J2.36, J2.37, J3.6 (GND), J3.9 (GND), J3.14 (GND), J3.20 (GND), J3.25 (GND), J3.30 (GND), J3.34 (GND), J3.39 (GND), J4.4, J4.10, J4.16, J4.25, J4.26, J4.38, J4.40, J5.1, J6.1, J7.4 (GND), J7.5 (Shield), J8.4 (GND), J8.5 (Shield), J9.4 (GND), J9.5 (Shield), R1.2, R2.2, R3.2, R64.2, R65.2, R80.1, TP5.1 (1_1), U1.2 (GND), U2.2 (A1), U2.3 (A2), U2.12 (GND), U2.21 (A0), U3.2 (A1), U3.3 (A2), U3.12 (GND), U4.2 (GND), U5.2 (GND), U6.2 (GND), U12.2 (GND); also elsewhere on the board
unnamed: D15.2 (A), U3.10 (P06)
unnamed: D15.1 (K), R64.1
unnamed: D16.2 (A), U3.11 (P07)
unnamed: D16.1 (K), R65.1
unnamed: D24.1 (K), J5.6, R24.1
unnamed: D48.1 (A1), F1.1, J1.A4 (VBUS), J1.A9 (VBUS), J1.B4 (VBUS), J1.B9 (VBUS)
unnamed: D49.2 (A), R77.1
unnamed: D50.2 (A), R78.1
unnamed: F2.1, J3.2 (5V), J3.4 (5V)
unnamed: F8.1, J3.1 (3V3), J3.17 (3V3)
unnamed: J1.A5 (CC1), R2.1
unnamed: J1.B5 (CC2), R3.1
unnamed: J1.A6 (D+), J1.B6 (D+), U12.4 (I/O2)
unnamed: J1.A7 (D-), J1.B7 (D-), U12.6 (I/O1)
unnamed: C1.2, J1.S1 (SHIELD), R1.1, R80.2
unnamed: F3.1, J4.37
unnamed: F4.1, J4.39
unnamed: F6.2, J5.2
unnamed: F5.2, J6.2

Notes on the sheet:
PiZero connector
0x1001000
USB-C connector
0x0100000
0x1001001
4 relays
0x0100001
8ch ADC 0-24V
Qwiic connector
TCA9535PWR PCA9535PWR TCA9555PWR PCA9555PWR PCA9535PW,118 PCA9555PW
Addons connector
RPi HAT connector
16ch GPIO 0-24V
USB hub & connectors
Adapter board connectors
USB4 available on J2 connector pins 39, 40

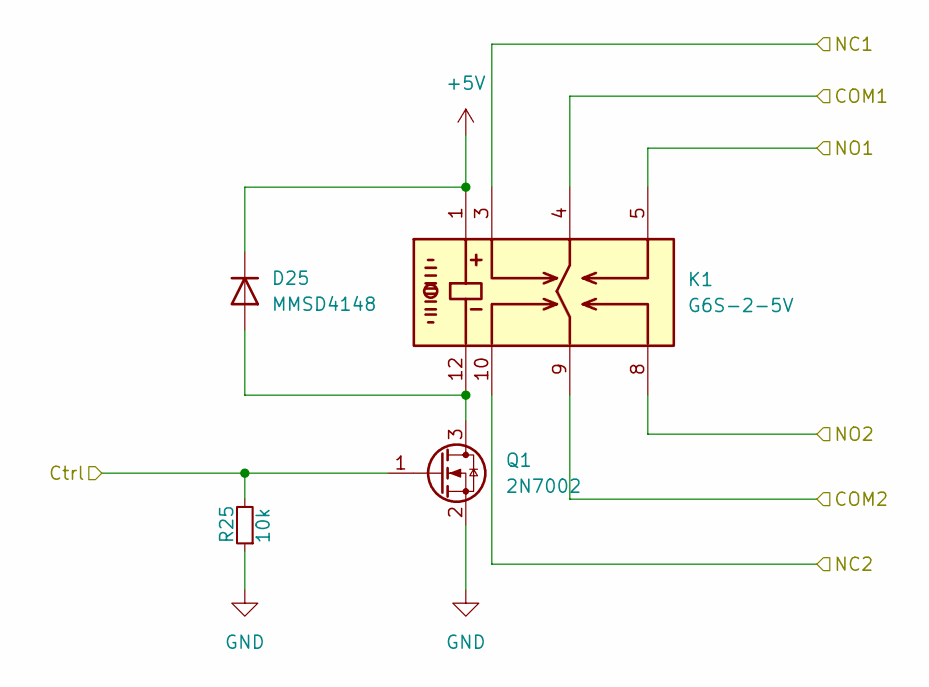
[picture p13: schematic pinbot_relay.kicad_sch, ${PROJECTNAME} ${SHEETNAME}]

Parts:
D25: MMSD4148; D_SOD-123; LCSC Part # C11177
K1: G6S-2-5V; Manufacturer Part G6S-2 DC5; LCSC Part # C32776
Q1: 2N7002; SOT-23; LCSC Part # C81445
R25: 10k; R_0603_1608Metric; Mouser Part # RMC1/16K1002DTP; LCSC Part # C98220

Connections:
+5V: D25.1 (K), K1.1; also elsewhere on the board
/RELAY4: Q1.1 (G), R25.2; also elsewhere on the board
/RELAY4/COM2: K1.9; also elsewhere on the board
/RELAY4/NC2: K1.10
/RELAY4/NO2: K1.8; also elsewhere on the board
/R_COM4: K1.4; also elsewhere on the board
/R_NC4: K1.3; also elsewhere on the board
/R_NO4: K1.5; also elsewhere on the board
GND: Q1.2 (S), R25.1; also elsewhere on the board
unnamed: D25.2 (A), K1.12, Q1.3 (D)

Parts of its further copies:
D26, D27, D28: MMSD4148; D_SOD-123; LCSC Part # C11177
K2, K3, K4: G6S-2-5V; Manufacturer Part G6S-2 DC5; LCSC Part # C32776
Q2, Q3, Q4: 2N7002; SOT-23; LCSC Part # C81445
R44, R45, R46: 10k; R_0603_1608Metric; Mouser Part # RMC1/16K1002DTP; LCSC Part # C98220

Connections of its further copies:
+5V: D26.1 (K), D27.1 (K), D28.1 (K), K2.1, K3.1, K4.1; also elsewhere on the board
/RELAY1: Q2.1 (G), R44.2; also elsewhere on the board
/RELAY1/COM2: K2.9; also elsewhere on the board
/RELAY1/NC2: K2.10
/RELAY1/NO2: K2.8; also elsewhere on the board
/RELAY2: Q3.1 (G), R45.2; also elsewhere on the board
/RELAY2/COM2: K3.9; also elsewhere on the board
/RELAY2/NC2: K3.10
/RELAY2/NO2: K3.8; also elsewhere on the board
/RELAY3: Q4.1 (G), R46.2; also elsewhere on the board
/RELAY3/COM2: K4.9; also elsewhere on the board
/RELAY3/NC2: K4.10
/RELAY3/NO2: K4.8; also elsewhere on the board
/R_COM1: K2.4; also elsewhere on the board
/R_COM2: K3.4; also elsewhere on the board
/R_COM3: K4.4; also elsewhere on the board
/R_NC1: K2.3; also elsewhere on the board
/R_NC2: K3.3; also elsewhere on the board
/R_NC3: K4.3; also elsewhere on the board
/R_NO1: K2.5; also elsewhere on the board
/R_NO2: K3.5; also elsewhere on the board
/R_NO3: K4.5; also elsewhere on the board
GND: Q2.2 (S), Q3.2 (S), Q4.2 (S), R44.1, R45.1, R46.1; also elsewhere on the board
unnamed: D26.2 (A), K2.12, Q2.3 (D)
unnamed: D27.2 (A), K3.12, Q3.3 (D)
unnamed: D28.2 (A), K4.12, Q4.3 (D)

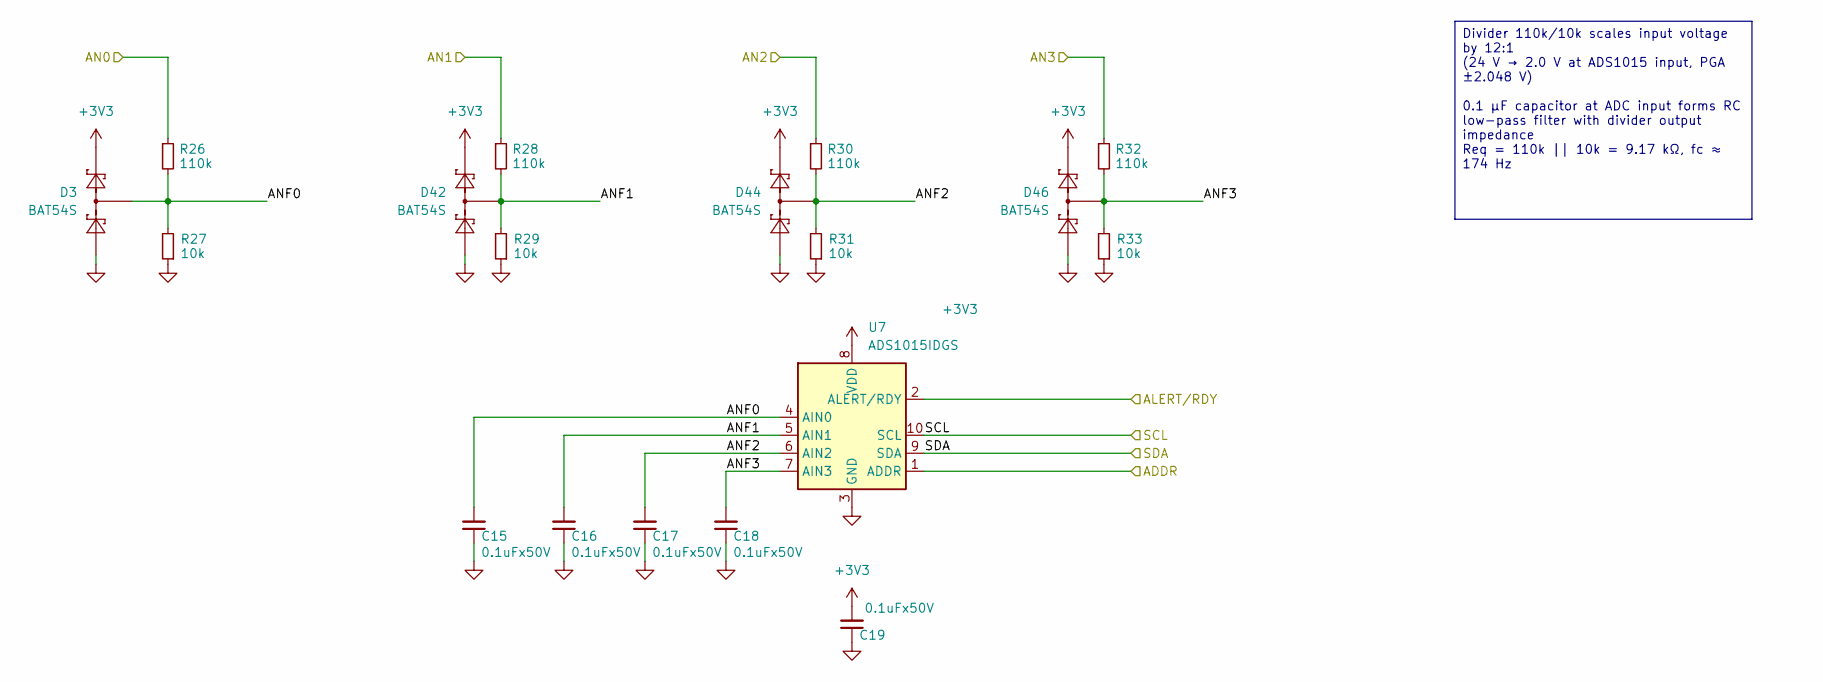
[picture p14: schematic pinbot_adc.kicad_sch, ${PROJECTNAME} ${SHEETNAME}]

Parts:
C15, C16, C17, C18, C19: 0.1uFx50V; C_0603_1608Metric; Mouser Part # CGA3E2X7R1H104M080AA; LCSC Part # C282519
D3, D42, D44, D46: BAT54S; SOT-23; LCSC Part # C19726
R26, R28, R30, R32: 110k; R_0603_1608Metric; Tolerance 1%; LCSC Part # C25805
R27, R29, R31, R33: 10k; R_0603_1608Metric; Tolerance 1%; Mouser Part # RMC1/16K1002DTP; LCSC Part # C98220
U7: ADS1015IDGS; TSSOP-10_3x3mm_P0.5mm; Mouser Part # ADS1015IDGS

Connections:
+3V3: C19.2, D3.2 (K), D42.2 (K), D44.2 (K), D46.2 (K), U7.8 (VDD); also elsewhere on the board
/ADC0/ANF0: C15.2, D3.3 (COM), R26.2, R27.2, U7.4 (AIN0)
/ADC0/ANF1: C16.2, D42.3 (COM), R28.2, R29.2, U7.5 (AIN1)
/ADC0/ANF2: C17.2, D44.3 (COM), R30.2, R31.2, U7.6 (AIN2)
/ADC0/ANF3: C18.2, D46.3 (COM), R32.2, R33.2, U7.7 (AIN3)
/ALERT0: U7.2 (ALERT/RDY); also elsewhere on the board
/AN0: R26.1; also elsewhere on the board
/AN1: R28.1; also elsewhere on the board
/AN2: R30.1; also elsewhere on the board
/AN3: R32.1; also elsewhere on the board
/RPi_GPIO2: U7.9 (SDA); also elsewhere on the board
/RPi_GPIO3: U7.10 (SCL); also elsewhere on the board
GND: C15.1, C16.1, C17.1, C18.1, C19.1, D3.1 (A), D42.1 (A), D44.1 (A), D46.1 (A), R27.1, R29.1, R31.1, R33.1, U7.1 (ADDR), U7.3 (GND); also elsewhere on the board

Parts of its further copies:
C20, C21, C22, C23, C24: 0.1uFx50V; C_0603_1608Metric; Mouser Part # CGA3E2X7R1H104M080AA; LCSC Part # C282519
D31, D43, D45, D47: BAT54S; SOT-23; LCSC Part # C19726
R35, R37, R39, R41: 110k; R_0603_1608Metric; Tolerance 1%; LCSC Part # C25805
R36, R38, R40, R42: 10k; R_0603_1608Metric; Tolerance 1%; Mouser Part # RMC1/16K1002DTP; LCSC Part # C98220
U8: ADS1015IDGS; TSSOP-10_3x3mm_P0.5mm; Mouser Part # ADS1015IDGS

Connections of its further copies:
+3V3: C24.2, D31.2 (K), D43.2 (K), D45.2 (K), D47.2 (K), U8.1 (ADDR), U8.8 (VDD); also elsewhere on the board
/ADC1/ANF0: C20.2, D31.3 (COM), R35.2, R36.2, U8.4 (AIN0)
/ADC1/ANF1: C21.2, D43.3 (COM), R37.2, R38.2, U8.5 (AIN1)
/ADC1/ANF2: C22.2, D45.3 (COM), R39.2, R40.2, U8.6 (AIN2)
/ADC1/ANF3: C23.2, D47.3 (COM), R41.2, R42.2, U8.7 (AIN3)
/ALERT1: U8.2 (ALERT/RDY); also elsewhere on the board
/AN4: R35.1; also elsewhere on the board
/AN5: R37.1; also elsewhere on the board
/AN6: R39.1; also elsewhere on the board
/AN7: R41.1; also elsewhere on the board
/RPi_GPIO2: U8.9 (SDA); also elsewhere on the board
/RPi_GPIO3: U8.10 (SCL); also elsewhere on the board
GND: C20.1, C21.1, C22.1, C23.1, C24.1, D31.1 (A), D43.1 (A), D45.1 (A), D47.1 (A), R36.1, R38.1, R40.1, R42.1, U8.3 (GND); also elsewhere on the board

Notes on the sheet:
Divider 110k/10k scales input voltage by 12:1 (24 V → 2.0 V at ADS1015 input, PGA ±2.048 V) 0.1 µF capacitor at ADC input forms RC low-pass filter with divider output impedance Req = 110k || 10k = 9.17 kΩ, fc ≈ 174 Hz

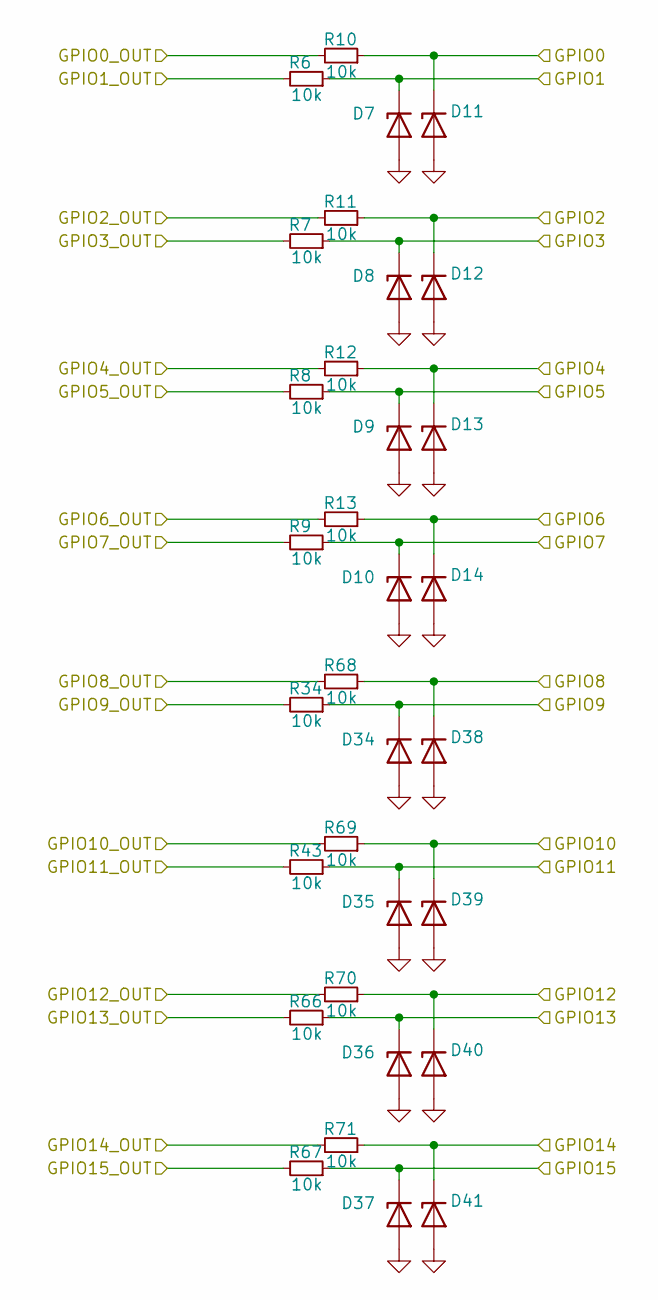
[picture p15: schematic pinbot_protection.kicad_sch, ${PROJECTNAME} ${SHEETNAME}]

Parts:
D7, D8, D9, D10, D11, D12, D13, D14, D34, D35, D36, D37, D38, D39, D40, D41: ESD5Z3.3T5G; D_SOD-523; Mouser Part # ESD5Z3.3T5G
R6, R7, R8, R9, R10, R11, R12, R13, R34, R43, R66, R67, R68, R69, R70, R71: 10k; R_0603_1608Metric; Mouser Part # RMC1/16K1002DTP; LCSC Part # C98220

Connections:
/GPIO0: D11.1 (K), R10.1; also elsewhere on the board
/GPIO0_OUT: R10.2; also elsewhere on the board
/GPIO1: D7.1 (K), R6.1; also elsewhere on the board
/GPIO1_OUT: R6.2; also elsewhere on the board
/GPIO2: D12.1 (K), R11.1; also elsewhere on the board
/GPIO2_OUT: R11.2; also elsewhere on the board
/GPIO3: D8.1 (K), R7.1; also elsewhere on the board
/GPIO3_OUT: R7.2; also elsewhere on the board
/GPIO4: D13.1 (K), R12.1; also elsewhere on the board
/GPIO4_OUT: R12.2; also elsewhere on the board
/GPIO5: D9.1 (K), R8.1; also elsewhere on the board
/GPIO5_OUT: R8.2; also elsewhere on the board
/GPIO6: D14.1 (K), R13.1; also elsewhere on the board
/GPIO6_OUT: R13.2; also elsewhere on the board
/GPIO7: D10.1 (K), R9.1; also elsewhere on the board
/GPIO7_OUT: R9.2; also elsewhere on the board
/GPIO8: D38.1 (K), R68.1; also elsewhere on the board
/GPIO8_OUT: R68.2; also elsewhere on the board
/GPIO9: D34.1 (K), R34.1; also elsewhere on the board
/GPIO9_OUT: R34.2; also elsewhere on the board
/GPIO10: D39.1 (K), R69.1; also elsewhere on the board
/GPIO10_OUT: R69.2; also elsewhere on the board
/GPIO11: D35.1 (K), R43.1; also elsewhere on the board
/GPIO11_OUT: R43.2; also elsewhere on the board
/GPIO12: D40.1 (K), R70.1; also elsewhere on the board
/GPIO12_OUT: R70.2; also elsewhere on the board
/GPIO13: D36.1 (K), R66.1; also elsewhere on the board
/GPIO13_OUT: R66.2; also elsewhere on the board
/GPIO14: D41.1 (K), R71.1; also elsewhere on the board
/GPIO14_OUT: R71.2; also elsewhere on the board
/GPIO15: D37.1 (K), R67.1; also elsewhere on the board
/GPIO15_OUT: R67.2; also elsewhere on the board
GND: D7.2 (A), D8.2 (A), D9.2 (A), D10.2 (A), D11.2 (A), D12.2 (A), D13.2 (A), D14.2 (A), D34.2 (A), D35.2 (A), D36.2 (A), D37.2 (A), D38.2 (A), D39.2 (A), D40.2 (A), D41.2 (A); also elsewhere on the board

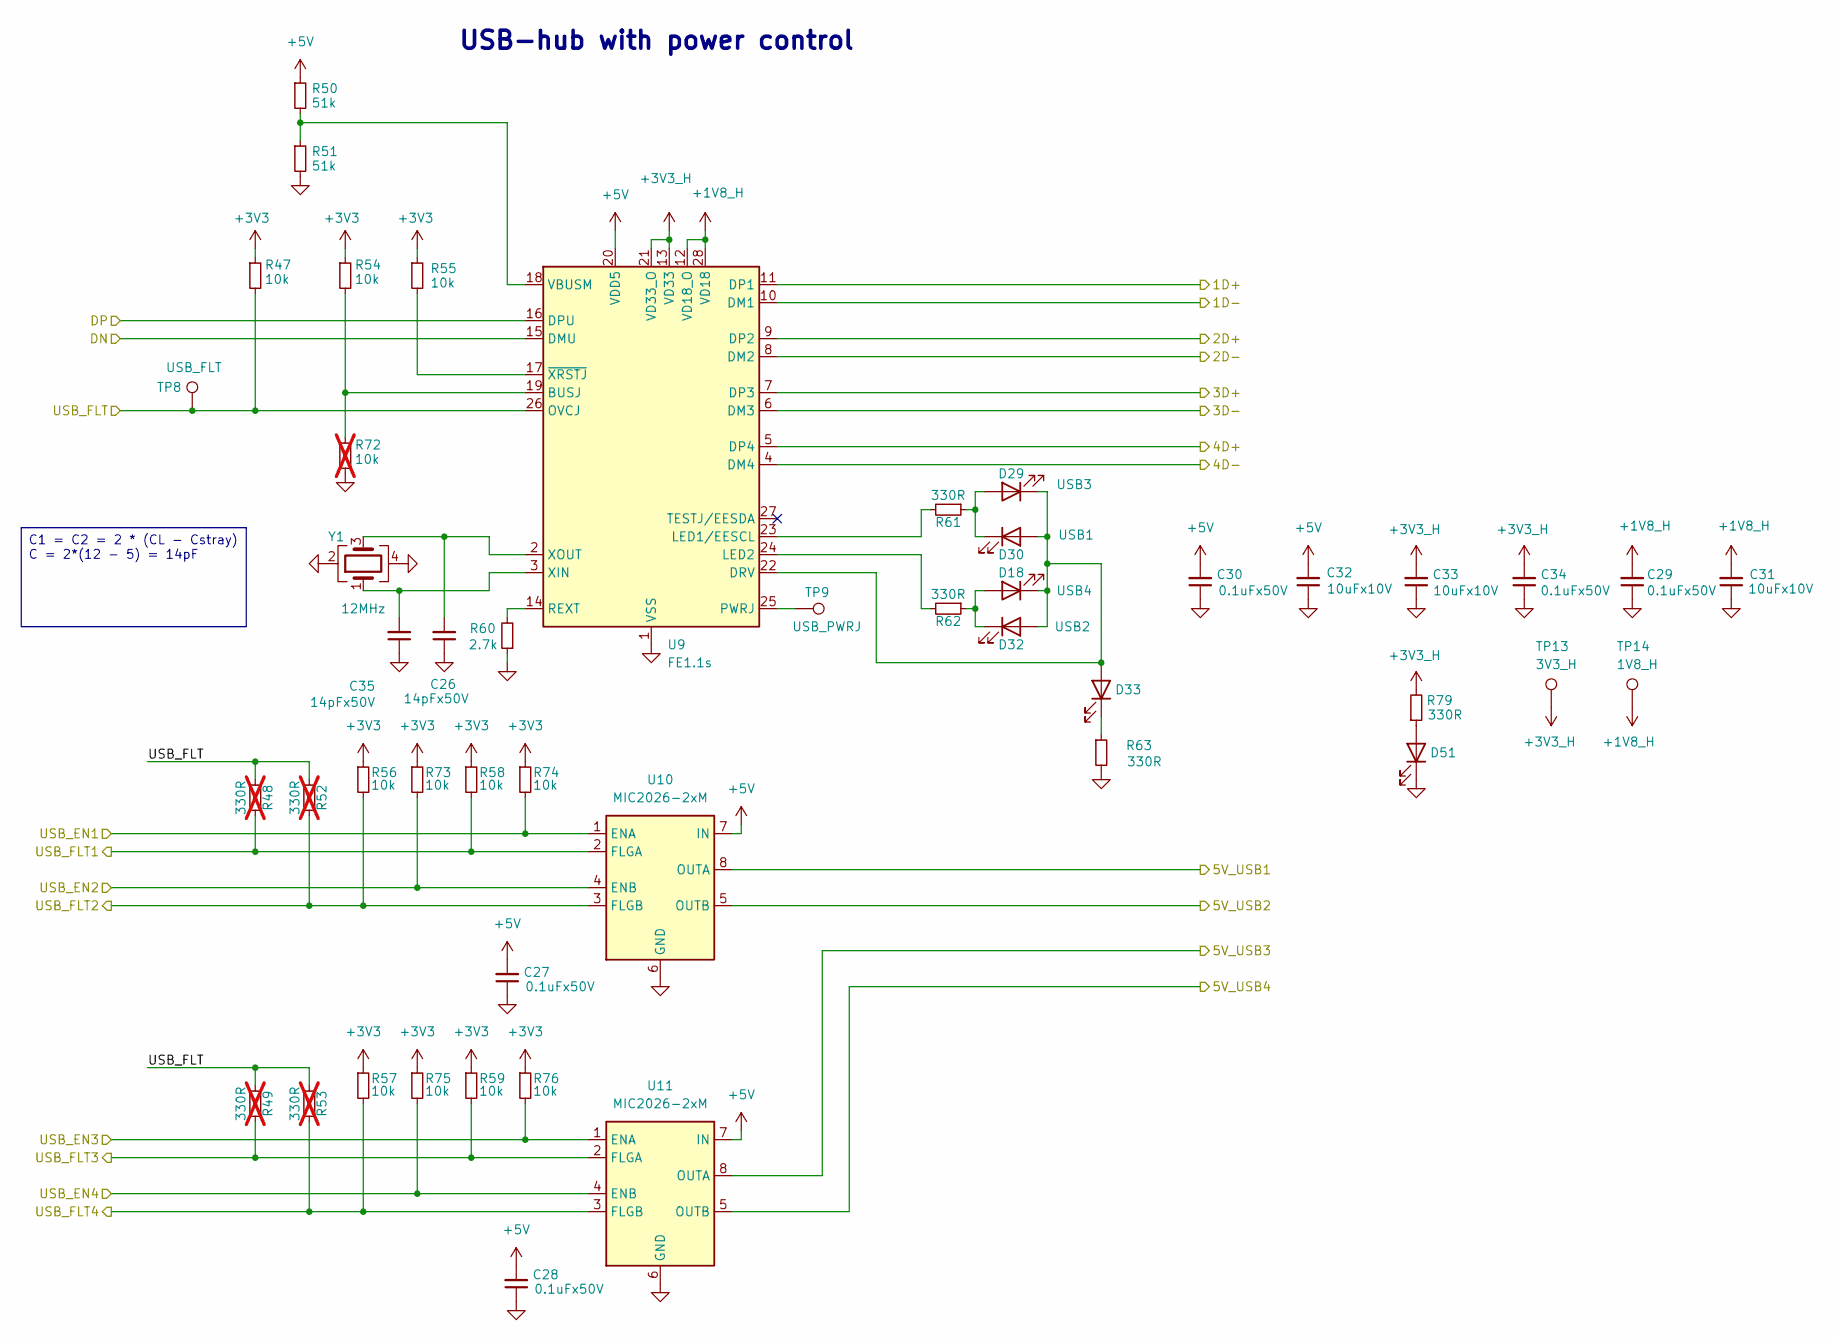
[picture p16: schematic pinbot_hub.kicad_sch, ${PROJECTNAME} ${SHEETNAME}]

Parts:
C26, C35: 14pFx50V; C_0603_1608Metric; LCSC Part # C5360816
C27, C28, C29, C30, C34: 0.1uFx50V; C_0603_1608Metric; Mouser Part # CGA3E2X7R1H104M080AA; LCSC Part # C282519
C31, C32, C33: 10uFx10V; C_0603_1608Metric; Mouser Part # GRM188Z71A106MA73J; LCSC Part # C2959727
D18: 19-21/GHC-YR1S2/4T; LED_0603_1608Metric; LCSC Part # C2986048
D29, D30, D32: LTST-S270KGKT; LED_0603_1608Metric_side; Mouser Part # LTST-S270KGKT; LCSC Part # C125113
D33, D51: XL-1608SURC-06; LED_0603_1608Metric; LCSC Part # C965799
R47, R54, R55, R56, R57, R58, R59, R73, R74, R75, R76: 10k; R_0603_1608Metric; Mouser Part # RMC1/16K1002DTP; LCSC Part # C98220
R48, R49, R52, R53: 330R; R_0603_1608Metric; Mouser Part # RMCF0603FT330R; LCSC Part # C23138; not fitted
R50, R51: 51k; R_0603_1608Metric; LCSC Part # C2907180
R60: 2.7k; R_0603_1608Metric; LCSC Part # C13167
R61, R62, R63, R79: 330R; R_0603_1608Metric; Mouser Part # RMCF0603FT330R; LCSC Part # C23138
R72: 10k; R_0603_1608Metric; Mouser Part # RMC1/16K1002DTP; LCSC Part # C98220; not fitted
TP8: USB_FLT; TestPoint_Loop_D1.80mm_Drill1.0mm_Beaded
TP9: USB_PWRJ; TestPoint_Loop_D1.80mm_Drill1.0mm_Beaded
TP13: 3V3_H; TestPoint_Loop_D1.80mm_Drill1.0mm_Beaded
TP14: 1V8_H; TestPoint_Loop_D1.80mm_Drill1.0mm_Beaded
U9: FE1.1s; SSOP-28_3.9x9.9mm_P0.635mm; Manufacturer Part FE1.1S-BSOP28BCN; LCSC Part # C9359
U10, U11: MIC2026-2xM; SOIC-8_3.9x4.9mm_P1.27mm; Mouser Part # MIC2026-2YM
Y1: 12MHz; Crystal_SMD_3225-4Pin_3.2x2.5mm; PartNumber X322512MOB4SI; LCSC Part # C70565

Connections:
+1V8_H: C29.2, C31.2, TP14.1 (1_1), U9.12 (VD18_O), U9.28 (VD18)
+3V3: R47.1, R54.1, R55.1, R56.1, R57.1, R58.1, R59.1, R73.1, R74.1, R75.1, R76.1; also elsewhere on the board
+3V3_H: C33.2, C34.2, R79.2, TP13.1 (1_1), U9.13 (VD33), U9.21 (VD33_O)
+5V: C27.2, C28.2, C30.2, C32.2, R50.1, U9.20 (VDD5), U10.7 (IN), U11.7 (IN); also elsewhere on the board
+5V_USB1: U10.8 (OUTA); also elsewhere on the board
+5V_USB2: U10.5 (OUTB); also elsewhere on the board
+5V_USB3: U11.8 (OUTA); also elsewhere on the board
+5V_USB4: U11.5 (OUTB); also elsewhere on the board
/1D+: U9.11 (DP1); also elsewhere on the board
/1D-: U9.10 (DM1); also elsewhere on the board
/2D+: U9.9 (DP2); also elsewhere on the board
/2D-: U9.8 (DM2); also elsewhere on the board
/3D+: U9.7 (DP3); also elsewhere on the board
/3D-: U9.6 (DM3); also elsewhere on the board
/4D+: U9.5 (DP4); also elsewhere on the board
/4D-: U9.4 (DM4); also elsewhere on the board
/RPI_D+: U9.16 (DPU); also elsewhere on the board
/RPI_D-: U9.15 (DMU); also elsewhere on the board
/USBHUB/USB_FLT: R47.2, R48.1, R49.1, R52.1, R53.1, TP8.1 (1_1), U9.26 (OVCJ)
/USB_EN1: R74.2, U10.1 (ENA); also elsewhere on the board
/USB_EN2: R73.2, U10.4 (ENB); also elsewhere on the board
/USB_EN3: R76.2, U11.1 (ENA); also elsewhere on the board
/USB_EN4: R75.2, U11.4 (ENB); also elsewhere on the board
/USB_FLT1: R48.2, R58.2, U10.2 (FLGA); also elsewhere on the board
/USB_FLT2: R52.2, R56.2, U10.3 (FLGB); also elsewhere on the board
/USB_FLT3: R49.2, R59.2, U11.2 (FLGA); also elsewhere on the board
/USB_FLT4: R53.2, R57.2, U11.3 (FLGB); also elsewhere on the board
GND: C26.1, C27.1, C28.1, C29.1, C30.1, C31.1, C32.1, C33.1, C34.1, C35.1, D51.1 (K), R51.2, R60.1, R63.2, R72.2, U9.1 (VSS), U10.6 (GND), U11.6 (GND), Y1.2, Y1.4; also elsewhere on the board
unnamed: D18.2 (A), D32.1 (K), R62.1
unnamed: D18.1 (K), D29.1 (K), D30.2 (A), D32.2 (A), D33.2 (A), U9.22 (DRV)
unnamed: D29.2 (A), D30.1 (K), R61.1
unnamed: D33.1 (K), R63.1
unnamed: D51.2 (A), R79.1
unnamed: R54.2, R72.1, U9.19 (BUSJ)
unnamed: R61.2, U9.23 (LED1/EESCL)
unnamed: R62.2, U9.24 (LED2)
unnamed: TP9.1 (1_1), U9.25 (PWRJ)
unnamed: R60.2, U9.14 (REXT)
unnamed: R50.2, R51.1, U9.18 (VBUSM)
unnamed: C35.2, U9.3 (XIN), Y1.1
unnamed: C26.2, U9.2 (XOUT), Y1.3
unnamed: R55.2, U9.17 (~XRSTJ)

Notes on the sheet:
USB-hub with power control
C1 = C2 = 2 * (CL - Cstray) С = 2*(12 - 5) = 14pF

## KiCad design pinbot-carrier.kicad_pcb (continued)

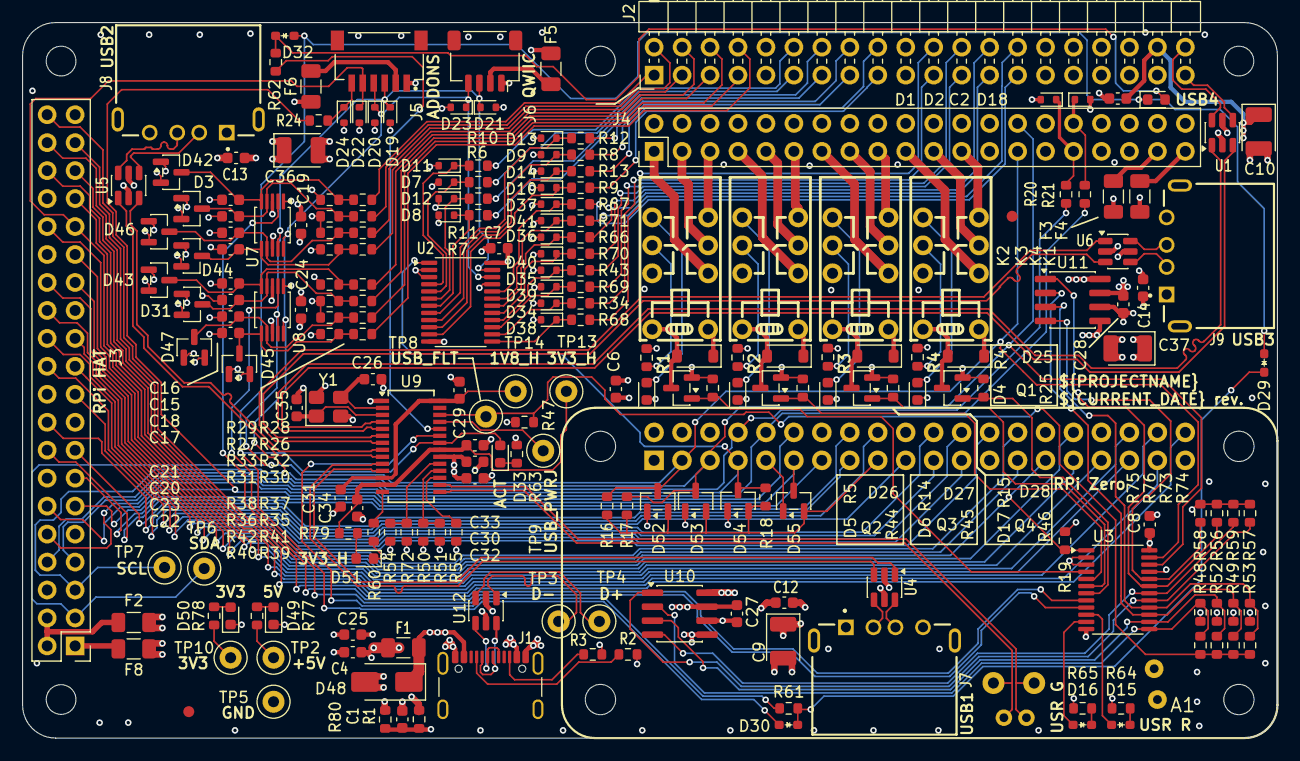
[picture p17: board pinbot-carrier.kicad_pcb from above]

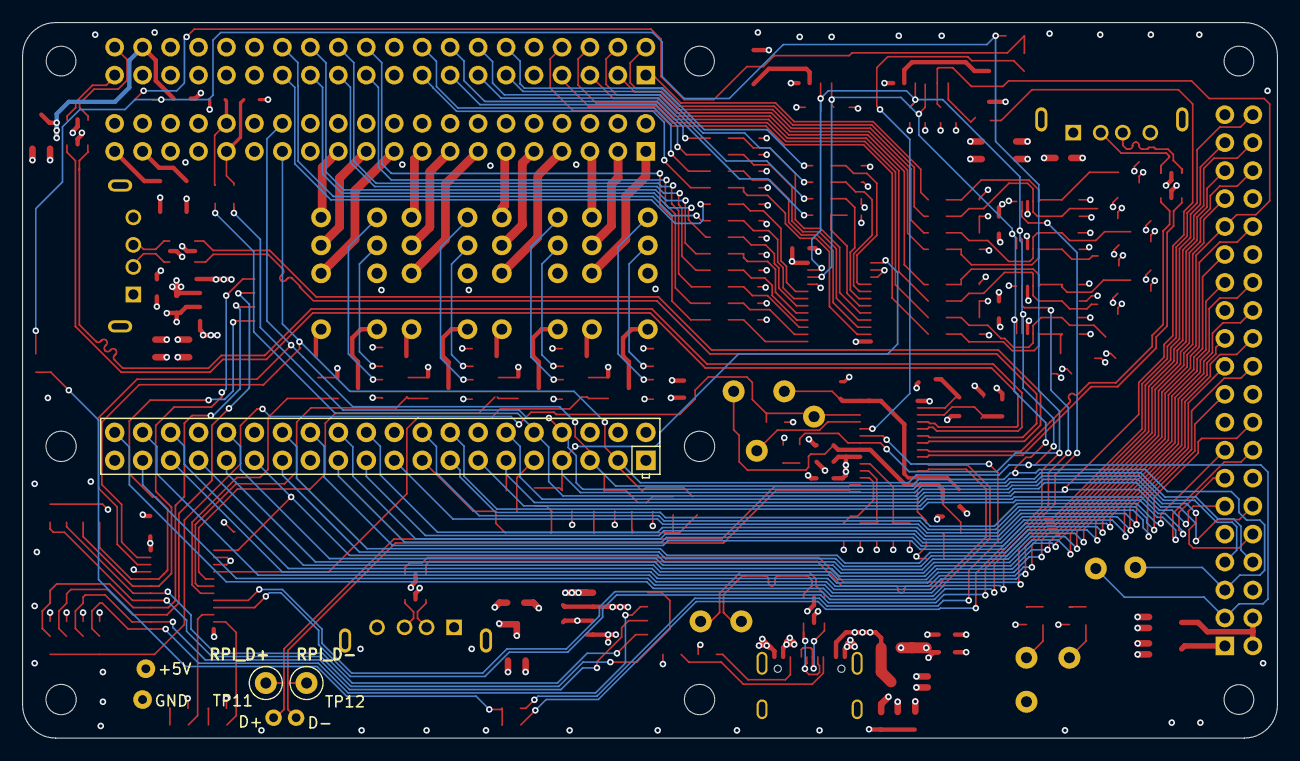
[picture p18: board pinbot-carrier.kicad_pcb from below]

Board: 4 copper layers, 114.0 x 65.0 mm, 224 parts (3 on the bottom side), 179 nets.

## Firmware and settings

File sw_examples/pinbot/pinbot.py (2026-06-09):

"""
Pinbot Board Control Library.
"""

import logging
import time
from .tca9535 import *

try:
    import lgpio
    LGPIO_AVAILABLE = True
except ImportError:
    LGPIO_AVAILABLE = False


class RelayControl:
    """
    Control helper for Pinbot relays.
    Relays 1-4 are mapped to io2 Port 0 Pins 0-3.
    """
    def __init__(self, board):
        self.board = board

    def open(self, relay_id):
        """
        Open (energize/turn on) a relay by setting the pin to HIGH.
        """
        if relay_id not in (1, 2, 3, 4):
            raise ValueError("Relay ID must be 1, 2, 3, or 4")
        pin = relay_id - 1
        self.board.io2.digital_write(0, pin, HIGH)

    def close(self, relay_id):
        """
        Close (de-energize/turn off) a relay by setting the pin to LOW.
        """
        if relay_id not in (1, 2, 3, 4):
            raise ValueError("Relay ID must be 1, 2, 3, or 4")
        pin = relay_id - 1
        self.board.io2.digital_write(0, pin, LOW)

    def open_all(self):
        """
        Open all 4 relays.
        """
        for relay_id in (1, 2, 3, 4):
            self.open(relay_id)

    def close_all(self):
        """
        Close all 4 relays.
        """
        for relay_id in (1, 2, 3, 4):
            self.close(relay_id)


# LED Constants
RED = "red"
GREEN = "green"


class LedControl:
    """
    Control helper for Pinbot user LEDs.
    Red LED is mapped to io2 Port 0 Pin 6.
    Green LED is mapped to io2 Port 0 Pin 7.
    """
    def __init__(self, board):
        self.board = board

    def _get_pin(self, led_id):
        if not isinstance(led_id, str):
            raise TypeError("LED ID must be a string ('RED' or 'GREEN')")
        norm_id = led_id.lower()
        if norm_id == "red":
            return 6
        elif norm_id == "green":
            return 7
        else:
            raise ValueError(f"Invalid LED ID: {led_id}. Must be 'RED' or 'GREEN'")

    def on(self, led_id):
        """
        Turn ON the specified LED.
        """
        pin = self._get_pin(led_id)
        self.board.io2.digital_write(0, pin, HIGH)

    def off(self, led_id):
        """
        Turn OFF the specified LED.
        """
        pin = self._get_pin(led_id)
        self.board.io2.digital_write(0, pin, LOW)

    def toggle(self, led_id):
        """
        Toggle the state of the specified LED.
        """
        pin = self._get_pin(led_id)
        # Read the current latch state from the shadow register cache
        current_state = (self.board.io2.get_output_port(0) >> pin) & 1
        new_state = LOW if current_state == HIGH else HIGH
        self.board.io2.digital_write(0, pin, new_state)


class UsbFaultError(Exception):
    """
    Exception raised when a USB port experiences a fault condition.
    """
    pass


class UsbControl:
    """
    Control helper for Pinbot USB Ports (Ports 1-4).
    Enables/disables ports and monitors fault status (active-low).
    """
    def __init__(self, board):
        self.board = board
        self.fault_occurred = [False, False, False, False, False]

    def _validate_port(self, port):
        if port not in (1, 2, 3, 4):
            raise ValueError("USB Port must be 1, 2, 3, or 4")

    def _get_pins(self, port):
        # EN is on Port 1, Pins 4-7
        # FLT is on Port 1, Pins 0-3
        en_pin = port + 3
        flt_pin = port - 1
        return en_pin, flt_pin

    def is_fault(self, port):
        """
        Check if a fault is active on the specified USB port.
        Since FLT is active-low, a fault is active when pin state is LOW (0).
        """
        self._validate_port(port)
        _, flt_pin = self._get_pins(port)
        return self.board.io2.digital_read(1, flt_pin) == LOW

    def enable(self, port):
        """
        Enable the specified USB port (active-low, write LOW).
        Raises UsbFaultError if a fault condition is detected immediately.
        """
        self._validate_port(port)
        en_pin, _ = self._get_pins(port)
        self.fault_occurred[port] = False

        # Enable by writing LOW (0)
        self.board.io2.digital_write(1, en_pin, LOW)

        # Give the overcurrent protection circuit (MIC2026) a tiny window (20ms)
        # to charge capacitors and trigger USB_FLT if there is a short circuit.
        time.sleep(0.02)

        # Check if a fault is active
        if self.is_fault(port):
            # Disable port immediately for safety
            self.disable(port)
            raise UsbFaultError(f"USB port {port} fault detected upon enablement")

    def disable(self, port):
        """
        Disable the specified USB port (active-low, write HIGH).
        """
        self._validate_port(port)
        en_pin, _ = self._get_pins(port)
        self.fault_occurred[port] = False

        # Disable by writing HIGH (1)
        self.board.io2.digital_write(1, en_pin, HIGH)
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

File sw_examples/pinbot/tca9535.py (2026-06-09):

import logging
import threading

import smbus2 as smbus


# TCA9535 registers config
# ============================================================================

INPUT_PORT_0 = 0x00
INPUT_PORT_1 = 0x01

OUTPUT_PORT_0 = 0x02
OUTPUT_PORT_1 = 0x03

POLARITY_PORT_0 = 0x04
POLARITY_PORT_1 = 0x05

CONFIG_PORT_0 = 0x06
CONFIG_PORT_1 = 0x07


# Constants
# ============================================================================

INPUT = 1
OUTPUT = 0

LOW = 0
HIGH = 1

DEFAULT_ADDRESS = 0x20


# TCA9535
# ============================================================================

class TCA9535:
    """
    TCA9535 16-bit I2C GPIO expander driver.

    Features:
    - Per-pin direction control
    - Per-pin read/write
    - Port read/write
    - Shadow register cache
    - Thread-safe access
    - Polarity inversion
    - Safe initialization
    """

    def __init__(
        self,
        i2c_address=DEFAULT_ADDRESS,
        bus_number=1,
    ):

        self.address = i2c_address
        self.bus = smbus.SMBus(bus_number)
        self.lock = threading.Lock()

        # --------------------------------------------------------------------
        # Read current register state to fill shadow cache
        # --------------------------------------------------------------------

        with self.lock:
            # 1. Read CONFIG
            config_port_0 = self._read_register(CONFIG_PORT_0)
            config_port_1 = self._read_register(CONFIG_PORT_1)
            self.config = [
                config_port_0 & 0xFF,
                config_port_1 & 0xFF,
            ]

            # 2. Read OUTPUT
            output_port_0 = self._read_register(OUTPUT_PORT_0)
            output_port_1 = self._read_register(OUTPUT_PORT_1)
            self.output = [
                output_port_0 & 0xFF,
                output_port_1 & 0xFF,
            ]

            # 3. Read POLARITY
            polarity_port_0 = self._read_register(POLARITY_PORT_0)
            polarity_port_1 = self._read_register(POLARITY_PORT_1)
            self.polarity = [
                polarity_port_0 & 0xFF,
                polarity_port_1 & 0xFF,
            ]

        logging.debug(
            f"TCA9535 initialized at 0x{self.address:02X} by reading physical registers"
        )

    # =========================================================================
    # Low-level I2C
    # =========================================================================

    def _write_register(self, register, value):
        self.bus.write_byte_data(
            self.address,
            register,
            value & 0xFF
        )

    def _read_register(self, register):
        return self.bus.read_byte_data(
            self.address,
            register
        )

    # =========================================================================
    # Validation
    # =========================================================================

    @staticmethod
    def _validate_port(port):
        if port not in (0, 1):
            raise ValueError("Port must be 0 or 1")

    @staticmethod
    def _validate_pin(pin):
        if not 0 <= pin <= 7:
            raise ValueError("Pin must be in range 0-7")

    @staticmethod
    def _validate_mode(mode):
        if mode not in (INPUT, OUTPUT):
            raise ValueError("Mode must be INPUT or OUTPUT")

    @staticmethod
    def _validate_state(state):
        if state not in (LOW, HIGH):
            raise ValueError("State must be LOW or HIGH")

    # =========================================================================
    # Direction control
    # =========================================================================

    def pin_mode(self, port, pin, mode):
        """
        Set pin direction.

        INPUT  = 1
        OUTPUT = 0
        """

        self._validate_port(port)
        self._validate_pin(pin)
        self._validate_mode(mode)

        with self.lock:

            if mode == INPUT:
                self.config[port] |= (1 << pin)
            else:
                self.config[port] &= ~(1 << pin)

            register = (
                CONFIG_PORT_0
                if port == 0
                else CONFIG_PORT_1
            )

            self._write_register(register, self.config[port])

    def set_port_direction(self, port, direction_mask):
        """
        Configure entire port.

        Bit:
            1 = INPUT
            0 = OUTPUT
        """

        self._validate_port(port)

        with self.lock:

            self.config[port] = direction_mask & 0xFF

            register = (
                CONFIG_PORT_0
                if port == 0
                else CONFIG_PORT_1
            )

            self._write_register(register, self.config[port])

    # =========================================================================
    # Digital write
    # =========================================================================

    def digital_write(self, port, pin, state):
        """
        Write pin state.

        Uses shadow registers to avoid read-modify-write races.
        """

        self._validate_port(port)
        self._validate_pin(pin)
        self._validate_state(state)

        with self.lock:

            if state == HIGH:
                self.output[port] |= (1 << pin)
            else:
                self.output[port] &= ~(1 << pin)

            register = (
                OUTPUT_PORT_0
                if port == 0
                else OUTPUT_PORT_1
            )

            self._write_register(register, self.output[port])

    def write_port(self, port, value):
        """
        Write entire 8-bit port.
        """

        self._validate_port(port)

        with self.lock:

            self.output[port] = value & 0xFF

            register = (
                OUTPUT_PORT_0
                if port == 0
                else OUTPUT_PORT_1
            )

            self._write_register(register, self.output[port])

    # =========================================================================
    # Digital read
    # =========================================================================

    def digital_read(self, port, pin):
        """
        Read physical pin state.
        """

        self._validate_port(port)
        self._validate_pin(pin)

        register = (
            INPUT_PORT_0
            if port == 0
            else INPUT_PORT_1
        )

        value = self._read_register(register)

        return HIGH if (value & (1 << pin)) else LOW

    def read_port(self, port):
        """
        Read physical 8-bit port state.
        """

        self._validate_port(port)

        register = (
            INPUT_PORT_0
            if port == 0
            else INPUT_PORT_1
        )

        return self._read_register(register)
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

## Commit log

2026-06-09 r0.2 remade from a scratch
    [20251119-BOM-pinbot-carrier.csv, __bom.csv, __designators.csv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]
2026-06-09 add manufacturing for rev.0.22
    [bom.csv, designators.csv, positions.csv]
2026-06-10 gitignore and power rating updates
2026-06-10 legacy gerbers cleanup
    [20251119-BOM-pinbot-carrier.csv, __bom.csv, __designators.csv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]
